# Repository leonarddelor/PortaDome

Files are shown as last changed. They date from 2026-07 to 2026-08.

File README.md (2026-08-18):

# PortaDome

Dôme démontable de **25 haut-parleurs** diffusant une bande son **synchronisée à l'échantillon
près** sur toutes les voies. Projet étudiant, ~1 an, rythme soutenu.

Le parti pris qui commande tout le reste : **une seule Teensy est le cerveau**, maître d'horloge
unique pour les 25 voies via 2 ports TDM. Rien d'autre n'a d'horloge propre — c'est ce qui interdit
la dérive entre haut-parleurs voisins.

---

## ⚠️ État au 2026-08-18 — à lire avant tout

Le dépôt contient **deux générations de carte ampli**. Ne pas les confondre :

| | Carte proto mono-puce | **Carte ampli v2** |
|---|---|---|
| État | Routée, gerbers vérifiés | **À concevoir** |
| Commandée ? | **Non, et ne le sera pas** | pas encore |
| Rôle aujourd'hui | **Référence** — valeurs vérifiées au datasheet et défauts trouvés | la carte qu'on construit |

**Le proto ne sera pas fabriqué.** Le projet a de l'avance, et une session de conception système le
18/08 a fait apparaître cinq écarts entre cette carte et ce dont le dôme a besoin — tous sur ses
**interfaces**, aucun visible en relisant son schéma. La refonte les corrige d'un coup.

Le document du proto reste précieux : il porte les valeurs vérifiées contre le datasheet et
l'historique des défauts trouvés, qui ne doivent pas être refaits.

---

## Ce qu'on construit

```
Ordinateur (USB)  ─┐
                   ├─► Teensy 4.1 ─TDM/I2C─► 3 cartes mères × 4 cartes ampli ─► 24 HP 8 Ω
Carte SD (secours) ─┘        (maître          + 1 carte MCU × 1 carte ampli   ─► 1 sub 4 Ω
                              d'horloge)         (PBTL)
```

Le tout dans un **rack 19" 3U ventilé**, cartes ampli **debout et débrochables**, sorties en
**Speakon NL4**. Budget estimé : **~920 $** hors haut-parleurs.

---

## Les documents

| Fichier | Ce qu'il contient |
|---|---|
| [`docs/architecture-systeme.md`](docs/architecture-systeme.md) | **Commencer par là.** Carte des décisions sur 9 sous-systèmes : ce qui est décidé, ce qui est ouvert, et le graphe de ce qui bloque quoi. |
| [`docs/proposition-carte-octo-dome.md`](docs/proposition-carte-octo-dome.md) | Proposition technique. Le §7 porte le cahier des charges de la carte ampli v2. |
| [`docs/mecanique-coffret.md`](docs/mecanique-coffret.md) | Rack 3U, cartes debout, ventilation push-pull, connectique. |
| [`docs/proto-ampli-tas5825m.md`](docs/proto-ampli-tas5825m.md) | Suivi du proto. **Le §7 liste les défauts trouvés** — à ne pas refaire. |
| [`docs/carte-adaptation.md`](docs/carte-adaptation.md) | Le slot de carte mère construit seul, pour tester les cartes ampli au banc. |
| [`docs/diagnostic-et-maintenance.md`](docs/diagnostic-et-maintenance.md) | Ce que les puces savent dire d'elles-mêmes, et le client USB de réglage et de dépannage. |
| [`docs/budget-coffret.html`](docs/budget-coffret.html) | Chiffrage par poste, avec niveau de confiance par ligne. |
| [`docs/projet-etudiant-feuille-de-route.md`](docs/projet-etudiant-feuille-de-route.md) | Méthode de travail, conventions git, glossaire. |
| [`mecanique/implantation-3u.scad`](mecanique/implantation-3u.scad) | Étude d'encombrement paramétrique. `F5` dans OpenSCAD, lire la console. |
| [`mecanique/references-step-et-cotes.md`](mecanique/references-step-et-cotes.md) | Où trouver chaque STEP, et quelles cotes sont vérifiées ou estimées. |

---

## Le travail à faire

Cinq chantiers. Les phases B et C **ne dépendent de rien** et peuvent démarrer immédiatement.

### A · Carte ampli v2 — le chemin critique

1. **Nettoyer le schéma existant.** Trois références LCSC manquantes (10 kΩ, 4,7 kΩ, 1 µF) et une
   contamination : la référence du 470 nF a été recopiée sur des lignes déclarées 100 nF et 680 nF.
   À corriger avant de dupliquer le projet, sinon ça se propage.
2. **Modifier le schéma** : router `PDN`, `FAULTZ`, `WARNZ` et `ADR` vers le connecteur ; supprimer
   CN1 et U3 ; passer les 22 µF PVDD en CMS ; strap PBTL **après** le filtre LC.
3. **Router en 4 couches**, plan GND continu en couche 2, connecteurs sur le bord inférieur
   (2×4 puissance + 2×8 signal), vias thermiques **dans l'empreinte** de U1.
4. **Exporter en STEP** → débloque la phase D et donne la cote la plus critique du projet : la
   hauteur du composant le plus haut, dont dépend le canal d'air de 8 mm entre cartes.
5. **Commander**, avec la carte d'adaptation ci-dessous.

### B · Carte d'adaptation 1 slot — à concevoir en parallèle

La carte v2 n'a plus de bornier : elle ne peut être testée qu'enfichée. Or la carte mère n'existera
pas avant des semaines, et les fils Dupont (~1 A) ne supportent ni les 3,4 A de PVDD ni les 2,1 A de
sortie.

Un petit 2 couches portant les deux embases femelles, un bornier PVDD, un bornier HP, un header
signaux vers XIAO ou Teensy 3.6, la résistance ADR et des trous de fixation. ~10 $ les 5.

**Cette carte est un slot de la carte mère.** La concevoir valide le circuit du slot avant de le
répliquer ×4 — c'est isoler les variables, pas faire un détour.

### C · Firmware et client — indépendants de tout le matériel

Peut démarrer aujourd'hui. Init I2C du TAS5825M à réécrire (le driver Sonocotta cible le TAS5805M),
configuration des GPIO0/1/2 en `WARNZ`/`FAULTZ` (registres `60h`-`63h`), I2S stéréo d'abord puis
TDM, répartition des slots conforme à `architecture-systeme.md` §4.

Côté ordinateur, un **client USB** de réglage et de dépannage (voir
[`diagnostic-et-maintenance.md`](docs/diagnostic-et-maintenance.md)). La Teensy n'est qu'un relais
I2C : toute l'intelligence est dans le client, ce qui permet d'itérer sur les réglages **sans
reflasher**.

### D · Mécanique — après l'export STEP

Assemblage FreeCAD à partir des vrais modèles (voir `mecanique/references-step-et-cotes.md`).
Vérifier en priorité le **canal d'air réel entre deux cartes voisines** : estimé à 8 mm, et le pas
de 20 mm ne peut pas être élargi sans faire déborder le rack.

### E · Carte mère ×4 — après validation du slot en phase B

4 couches avec plan PVDD (13,6 A pour 4 slots), buck 24 V → 3,3 V, multiplexeur I2C, `FAULTZ`/`WARNZ`
câblés en OU, adressage par slot.

---

## Les deux décisions qui débloquent le plus

1. **Choisir le haut-parleur.** L'impédance est figée (8 Ω), le modèle non. Budget d'alimentation,
   section des câbles et géométrie du châssis en dépendent tous.
2. **Acheter ou fabriquer le châssis.** L'écart va de 60 à 250 $, soit près de 20 % du budget.

## Le piège connu

**~10 mF de capacité de réserve cumulée** sur 13 cartes. Une alimentation de 350 W part en sécurité
ou fait disjoncter au premier allumage, et aucune précharge n'est prévue. C'est le seul défaut de la
liste qui se manifeste par « rien ne démarre » sans indiquer sa cause. Solution notée : séquencer
les 3 cartes mères à ~200 ms d'écart, plus une NTC.

---

## Conventions

Un commit = une idée ; le message explique **pourquoi**, pas seulement quoi. Toute affirmation
matérielle (broche, référence, valeur de registre) se recoupe contre le datasheet officiel — y
compris celles produites par un assistant. **La mesure gagne sur l'affirmation.** Les décisions se
consignent dans les documents datés, pas dans un historique de conversation.

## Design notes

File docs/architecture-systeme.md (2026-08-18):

# Architecture système — carte des décisions

> Document créé le 2026-08-18. Complément de [`proposition-carte-octo-dome.md`](./proposition-carte-octo-dome.md)
> (la proposition technique) et de [`proto-ampli-tas5825m.md`](./proto-ampli-tas5825m.md) (le suivi
> de la carte ampli). Ceux-là décrivent **ce qu'on fait** ; celui-ci décrit **où on en est et ce qui
> bloque quoi**.

## 0. Pourquoi ce document

Le 2026-08-18, une conversation sur la finalité du système a fait apparaître cinq déviations entre
ce qui était conçu et ce dont le projet a besoin : PDN non routé, connecteur à une seule masse, carte
sub bridgée incompatible avec le choix 8 Ω, origine du 3,3 V non tranchée, selfs sous la spec TI.

**Aucune ne venait de la relecture du schéma ou du PCB.** Toutes sont des questions d'**interface**,
et chaque bloc était correct isolément. C'est la raison d'être de ce document : rendre visibles les
frontières entre sous-systèmes, parce que c'est là que se logent les erreurs qu'aucune DRC ne voit.

**Comment le lire** : chaque sous-système donne ce qui est **décidé**, ce qui est **ouvert**, et
**ce dont il dépend**. La §10 donne l'ordre dans lequel les décisions doivent tomber.

## 1. Vue d'ensemble

```
   Source audio                 Cerveau                Distribution           Puissance      Acoustique
  ┌────────────┐          ┌────────────────┐      ┌──────────────────┐    ┌──────────┐   ┌──────────┐
  │ Ordinateur │──USB────►│                │      │ Carte mère 1     │───►│ 4× ampli │──►│ 8 HP     │
  │ (DAW/Max)  │          │  Teensy 4.1    │─TDM─►│ Carte mère 2     │───►│ 4× ampli │──►│ 8 HP     │
  └────────────┘          │  maître        │ I2C  │ Carte mère 3     │───►│ 4× ampli │──►│ 8 HP     │
  ┌────────────┐          │  d'horloge     │      │ Carte MCU        │───►│ 1× ampli │──►│ 1 sub    │
  │ Carte SD   │─────────►│                │      └──────────────────┘    └──────────┘   └──────────┘
  └────────────┘          └────────────────┘                 ▲
                                                             │
                                              ┌──────────────┴───────────────┐
                                              │  Alim 24 V  +  3,3 V         │
                                              └──────────────────────────────┘
```

25 voies = 24 (3 × 8) + 1 caisson.

## 2. Haut-parleurs

**C'est le bloc qui commande tous les autres, et c'est le moins avancé.**

- ✅ **Décidé** : **8 Ω**, figé le 2026-08-18. 25 transducteurs (24 + 1 caisson).
- ❌ **Ouvert** : modèle, puissance admissible, rendement, diamètre, profondeur, type de fixation,
  impédance du caisson (4 Ω ou 8 Ω — voir §3).
- ⛔ **Bloque** : le budget d'alimentation (§6), la section des câbles (§7), la géométrie du châssis
  (§8), et la puissance réellement utile par voie.

**Repère de dimensionnement** : la chaîne délivre **~30 W/voie** à 8 Ω sous 24 V (datasheet
Figure 10-2, 1 % THD). Un HP admettant moins que ça en continu devient le facteur limitant ; un HP
admettant beaucoup plus est de l'argent dépensé pour rien.

## 3. Chaîne d'amplification

- ✅ **Décidé** : TAS5825M, 13 cartes (12 + 1 sub), topologie 3+1, ~30 W/voie, carte sub identique
  aux autres avec strap PBTL + réglage registre, parallélisation **après** les selfs.
- ❌ **Ouvert** : les 8 points du cahier des charges et les 4 décisions de routage, tous détaillés en
  [spec §7](./proposition-carte-octo-dome.md).
- ⚠️ **Le proto mono-puce ne sera pas commandé** (voir [proto §0](./proto-ampli-tas5825m.md)). On
  passe directement à la carte définitive.
- ⚠️ **Carte d'adaptation 1 slot à concevoir** — relevé le 2026-08-18. En supprimant CN1 et U3, la
  carte v2 perd ses deux seuls points de branchement : elle ne peut plus être testée qu'enfichée.
  Or la carte mère n'existera pas avant des semaines, et les fils Dupont (~1 A) ne supportent ni les
  3,4 A de PVDD ni les 2,1 A de sortie HP. Il faut donc un petit 2 couches portant les deux embases
  femelles, un bornier PVDD, un bornier HP, un header signaux vers XIAO ou Teensy 3.6, la résistance
  ADR et des trous de fixation (~10 $ les 5).
  **Cette carte est un slot de la carte mère** : la concevoir valide le circuit du slot avant de le
  répliquer ×4. Voir le plan de travail du [README](../README.md).
- ⚠️ **Selfs sous-spécifiées** : TI demande 4,4 A, la référence retenue donne 3,1 A nominal.

**Point d'arbitrage restant** : **caisson en 4 Ω ou 8 Ω ?** Le PBTL ne sert qu'en dessous de 4 Ω. En
8 Ω, ne pas bridger et garder la seconde voie de cette carte libre. Dépend de §2.

## 4. Cartes mères

Le sous-système **le moins spécifié alors qu'il porte le plus d'interfaces**. Rien n'en existe
aujourd'hui, ni schéma ni cahier des charges.

- ✅ **Décidé** : 3 cartes mères de 4 slots + 1 carte MCU portant 1 slot. Chacune porte le buck
  24 V → 3,3 V de ses cartes ampli, le strapping ADR par slot, et le câblage en OU des FAULTZ/WARNZ.
- ❌ **Ouvert** : tout le reste — dimensions, connectique d'entrée, distribution PVDD interne,
  fan-out du bus TDM vers 4 slots, fixation mécanique des cartes ampli.

**Deux conséquences de la topologie 3+1, jamais notées jusqu'ici :**

**Adressage I2C.** Le TAS5825M n'offre que 4 adresses (0x4C-0x4F) pour 13 puces. La topologie les
résout élégamment : **une carte mère = un segment de mux**, 4 adresses par segment. Un seul
**TCA9548A** (8 segments) suffit — 3 segments pour les cartes mères, 1 pour le sub, 4 en réserve.
La spec §7 évoquait « 2 mux, ou regrouper » : le besoin est en fait d'**un seul**.

**Répartition des slots TDM.** 12 cartes × 2 voies + 1 sub en mono (**une seule voie**, pas deux)
= **25 slots**, pour 2 ports de 16 :

| Port | Contenu | Slots |
|---|---|---|
| TDM 1 | Cartes mères 1 et 2 | 16 |
| TDM 2 | Carte mère 3 + carte MCU (sub) | 9 |

25 slots pour 25 haut-parleurs, avec 7 slots de réserve sur le port 2. **À vérifier au firmware** :
le découpage doit correspondre au câblage physique, sinon une carte mère entière écoute les mauvais
slots.

## 5. Cerveau (MCU)

- ✅ **Décidé** : **Teensy 4.1** pour le système final, **Teensy 3.6** pour le banc ×4 (déjà en
  possession). Toujours maître d'horloge, quelle que soit la source. 2 ports TDM.
- ❌ **Ouvert** : **comment le bus TDM atteint physiquement 3 cartes mères séparées.** Voir §7 —
  c'est la question qui décide de l'implantation générale.

## 6. Alimentation

Voir [spec §8](./proposition-carte-octo-dome.md) pour le détail.

- ✅ **Décidé** : rail **24 V**. **3,3 V produit par chaque carte mère** (buck 24 V → 3,3 V), ni sur
  la carte ampli, ni depuis le régulateur de bord du MCU.
- ❌ **Ouvert** : précharge, distribution, protection, modèle d'alimentation.

**Le point qui mordra en premier** : ~10 mF de capacité de réserve cumulée sur 13 cartes. Une alim de
600 W part en sécurité ou fait disjoncter au premier allumage. Aucune précharge n'est prévue.
C'est le seul défaut de la liste qui se manifeste par « rien ne démarre », sans indiquer sa cause.

**Budget à recalculer** : les 500-600 W de la spec ont été estimés sur ~38 W/voie. À 30 W réels, le
budget descend. Dépend de §2 (puissance admissible des HP).

## 7. Câblage et implantation

**La décision structurante n'est écrite nulle part : les amplis sont-ils centralisés ou répartis
dans le dôme ?**

| | Ce qui voyage | Difficulté |
|---|---|---|
| **Amplis centralisés** (recommandé) | 25 câbles HP analogiques | Facile — voir barème ci-dessous |
| **Amplis répartis** | Bus TDM à 5-12 MHz sur plusieurs mètres | Difficile, et fragile |

L'analogique se transporte, le TDM rapide non. **Centraliser les 4 cartes dans un coffret** et tirer
du câble HP est la seule implantation qui tienne — mais tant que ce n'est pas écrit, rien ne
l'impose.

- ✅ **Décidé (implicitement, à confirmer)** : câble HP en **1,5 mm²**, **chaque paire torsadée**
  (+ et − du même HP enroulés ensemble — les champs s'annulent, c'est gratuit et c'est la mesure
  anti-rayonnement la plus efficace).
- ❌ **Ouvert** : câblage TDM/I2C entre carte MCU et cartes mères (longueurs, connecteurs, blindage),
  distribution 24 V (topologie étoile ou bus, sections), cheminement.

**Barème câble HP** (résistance aller-retour ≤ 5 % de l'impédance) :

| Section | Longueur max en 8 Ω |
|---|---|
| 0,75 mm² | 8,6 m |
| 1,5 mm² | 17 m |
| 2,5 mm² | 29 m |

Pour un dôme, les liaisons feront 1 à 5 m : **très large en 1,5 mm²**. La longueur n'est pas la
contrainte, le rayonnement l'est — d'où la torsade.

⚠️ Ne pas faire cheminer les câbles HP en parallèle serré avec le bus TDM/I2C ; les croiser à angle
droit si nécessaire.

## 8. Châssis et mécanique

**Entièrement ouvert.** Aucune décision prise, et plusieurs autres blocs en dépendent.

- Structure du dôme : géométrie, matériau, fixation des 25 HP
- Coffret électronique : implantation des 3 cartes mères + carte MCU + alimentation
- **Flux d'air** — la spec §8 le mentionne comme nécessaire, rien n'est conçu
- Fixation des cartes ampli sur les cartes mères : connecteur seul, ou connecteur + vis ?

⚠️ L'entraxe **45 × 51 mm** figé sur le proto n'a de sens que si la carte définitive garde
54,6 × 60,3 mm. Voir §3.

## 9. Source audio et firmware

- ✅ **Décidé** : USB depuis un ordinateur (mode principal), carte SD en socle et secours. Le Teensy
  reste maître d'horloge dans les deux cas.
- ❌ **Ouvert** : init I2C du TAS5825M à réécrire (le driver Sonocotta cible le TAS5805M), lecteur
  multicanal entrelacé démultiplexant vers `AudioOutputTDM`/`AudioOutputTDM2`, configuration des
  GPIO0/1/2 en WARNZ/FAULTZ (registres 0x60h-0x63h), répartition des slots conforme à §4.

**Le firmware ne dépend d'aucun choix matériel restant** — il peut démarrer immédiatement, en
parallèle de la conception des cartes.

## 10. Ordre des décisions

Les flèches se lisent « bloque ».

```
  [2] Haut-parleurs ─┬─► [6] Budget alim ────► modèle d'alimentation
   (8 Ω figé,        ├─► [7] Section câbles
    modèle ouvert)   ├─► [8] Géométrie châssis
                     └─► [3] Sub 4 Ω ou 8 Ω ──► bridger ou non

  [7] Centralisé ou réparti ──► [8] Coffret ──► [4] Dimensions cartes mères
                             └─► [5] Câblage TDM

  [3] 4 décisions de routage ──► [4] Connectique carte mère ──► [8] Fixation
```

**Premier domino : choisir le haut-parleur.** Tant qu'il n'est pas choisi, le budget d'alimentation,
la section des câbles et la géométrie du châssis restent des estimations sans ancrage.

**Deuxième : trancher centralisé vs réparti.** Une ligne dans un document, et elle décide de toute
l'implantation.

Ces deux-là ne coûtent rien à décider et débloquent presque tout le reste.

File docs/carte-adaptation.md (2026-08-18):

# Carte d'adaptation 1 slot

> Créé le 2026-08-18. Petit circuit 2 couches qui reçoit **une** carte ampli v2 et lui donne des
> points de branchement utilisables sur un établi.
>
> Voir [`mecanique-coffret.md`](./mecanique-coffret.md) §4 pour le brochage des connecteurs et
> [`proposition-carte-octo-dome.md`](./proposition-carte-octo-dome.md) §7 pour le cahier des charges
> de la carte ampli.

## 1. Le problème qu'elle résout

En rendant la carte ampli **débrochable**, on lui a retiré ses deux seuls points de branchement :
CN1 (bornier haut-parleur) et U3 (bornier PVDD) disparaissent. Il ne reste que deux embases 2,54 mm
destinées à la carte mère.

Or la carte mère n'existera pas avant des semaines, et il faut bien tester les cartes ampli à leur
réception.

**Les fils Dupont ne peuvent pas faire le pont** : ils sont donnés pour **~1 A**, alors que PVDD
demande **3,4 A** et chaque sortie haut-parleur **2,1 A**. Les signaux numériques passeraient, la
puissance non.

## 2. Elle a trois métiers

C'est ce qui la rend facile à justifier : une seule carte à 2 $ répond à trois besoins distincts.

| | |
|---|---|
| **Banc de test** | éprouver chaque carte ampli à sa réception, avant montage |
| **Prototype de slot** | valider le circuit du slot avant de le répliquer ×4 sur la carte mère |
| **Support d'usage autonome** | ⭐ rendre **une** carte ampli utilisable dans un autre projet |

### Le troisième métier répond à une contrainte déjà posée

Le §6 du document proto énonce que le bloc ampli doit servir **à d'autres projets, où l'on n'en a
besoin que d'une**. Or les décisions du 18/08 avaient discrètement érodé cette possibilité : en
supprimant CN1 et U3 pour rendre la carte débrochable, on l'a rendue inutilisable seule.

La carte d'adaptation restaure exactement cette capacité — et ce n'est pas un hasard, puisqu'une
carte ampli autonome a besoin de la même chose qu'un slot de banc : un bornier PVDD, un bornier
haut-parleur, un accès aux signaux numériques et une adresse I2C.

**Conséquence de conception** : la traiter comme une carte de production, pas comme un bricolage de
banc. Format compact, trous de fixation utilisables, sérigraphie lisible. Et prévoir une **empreinte
de buck 24 V → 3,3 V non peuplée par défaut** : sur carte mère le 3,3 V vient d'en haut, mais dans
un projet autonome l'hôte n'a pas forcément le budget de courant nécessaire. Une empreinte vide ne
coûte rien et rend la paire ampli + adaptation **autosuffisante à partir du seul 24 V**.

## 3. Ce qu'elle est, techniquement

**Un slot de carte mère, construit seul.**

Le circuit du slot — brochage des deux connecteurs, strapping ADR, distribution du 3,3 V, câblage en
OU des FAULTZ/WARNZ — doit être conçu de toute façon. La seule question est de savoir **sur quoi on
le valide** :

| | Sur cette carte | Directement sur la carte mère |
|---|---|---|
| Coût unitaire | ~2 $ | ~28 $ |
| Si le slot a une erreur | on refait une carte à 2 $ | l'erreur est répliquée **4 fois sur 3 cartes**, soit 12 slots faux |
| Correction | une commande | une commande **et** un routage 4 couches à reprendre |

C'est le raisonnement du §1 du document proto — prototyper **une** puce avant quatre. Isoler les
variables, payer l'erreur au prix le plus bas.

Ce n'est donc pas du travail en plus, c'est du **travail avancé** : le schéma se copie-colle ensuite
dans la carte mère.

## 4. Ce qu'elle porte

| Fonction | Composant | Note |
|---|---|---|
| Réception de la carte ampli | 2 embases femelles 2,54 mm (2×4 + 2×8) | le couple accouplé de la carte mère |
| Entrée PVDD | bornier à vis 2P 5,08 mm | `C395868`, déjà en stock — l'ancien U3 |
| Sorties haut-parleur | bornier à vis 4P 5,08 mm | `C2827883`, déjà en stock — l'ancien CN1 |
| Signaux vers MCU | header 2,54 mm simple rangée | fils Dupont vers XIAO S3 ou Teensy 3.6 |
| Adresse I2C | résistance ADR + pont de soudure | valide le mécanisme d'adressage par slot |
| Maintien mécanique | 4 trous M3 | la carte ampli tient debout sur l'établi |
| **Sélection de la source 3,3 V** | cavalier | ⚠️ **hôte OU buck local, jamais les deux** — voir ci-dessous |

⚠️ **Le cavalier 3,3 V n'est pas un confort, c'est une sécurité.** Si l'empreinte du buck est peuplée
*et* que l'hôte fournit son propre 3,3 V par le header, deux régulateurs se retrouvent en opposition
sur le même rail. Le cavalier rend le choix exclusif et visible. Cas typique : branché sur un
Raspberry Pi, on préfère le buck local plutôt que de charger le régulateur du Pi — seule la masse
est alors commune.

**Ajouts propres au banc, à ne jamais mettre dans le rack :**

- **Piquets de test sur BCLK, LRCLK, SDIN** — la §4 du document proto exige déjà une vérification à
  l'oscilloscope (« fronts propres sur BCLK/WS/DATA »). C'est ici qu'on les sort.
- **LED sur FAULTZ et sur WARNZ** — un défaut se voit sans brancher d'ordinateur.
- **Connecteur pour analyseur logique** sur le bus I2C — indispensable pour déboguer l'init du
  TAS5825M, qui est à réécrire entièrement.

## 5. Brancher un hôte

La carte doit servir trois hôtes différents — XIAO ESP32-S3 (le banc documenté en §4 du document
proto), Raspberry Pi, et Teensy 3.6 puis 4.1. Ils n'ont ni le même connecteur ni le même brochage.

**La solution : deux points d'accès câblés sur les mêmes nets**, dont un seul est utilisé à la fois.

| Accès | Format | Pour qui |
|---|---|---|
| **Support XIAO** | embase femelle 2×7, pas 2,54 mm | le XIAO ESP32-S3 s'y enfiche directement |
| **Header générique** | 1×10 ou 2×5, pas 2,54 mm, sérigraphié | Raspberry Pi, Teensy, tout le reste — en Dupont |

⚠️ **Une seule source d'horloge à la fois.** C'est BCLK/LRCLK/SDIN qui ne doivent jamais avoir deux
émetteurs — pas les autres signaux. En mode nœud de production (§6), un Pi et un ESP32 cohabitent
très bien : ils se partagent les rôles au lieu de se disputer le bus. À sérigraphier.

### XIAO ESP32-S3 — enfiché directement

C'est l'hôte principal du banc, et le seul assez petit pour être porté par la carte d'adaptation.
Brochage repris du §4 du document proto, déjà vérifié contre le pinout officiel Seeed :

| Signal | Broche XIAO |
|---|---|
| BCLK | D0 |
| LRCLK (WS) | D1 |
| SDIN (DATA) | D3 |
| SDA | D4 |
| SCL | D5 |
| PDN | **D8** |
| FAULTZ | **D9** |
| WARNZ | **D10** |

D2 est évité (broche de strapping), D6 et D7 restent libres pour garder le moniteur série de debug.
⚠️ Les trois dernières lignes (D8-D10) sont **à vérifier contre le pinout Seeed** avant routage,
comme l'ont été les cinq premières.

**Un atout de l'ESP32-S3** : ses broches I2S ne sont pas figées, elles se choisissent en firmware
via la matrice GPIO. Le routage de la carte peut donc privilégier la propreté du tracé, le firmware
s'adapte — à condition de respecter les broches interdites ci-dessus.

**Source 3,3 V** : cavalier sur « hôte ». Le régulateur du XIAO suffit pour le DVDD d'une seule puce.

### Raspberry Pi — par le header générique

Six signaux plus la masse, vers le connecteur 40 broches :

| Signal | GPIO | Broche Pi | Rôle |
|---|---|---|---|
| BCLK | GPIO18 | **12** | `PCM_CLK` |
| LRCLK | GPIO19 | **35** | `PCM_FS` |
| SDIN | GPIO21 | **40** | `PCM_DOUT` (sortie du Pi) |
| SDA | GPIO2 | **3** | `SDA1` |
| SCL | GPIO3 | **5** | `SCL1` |
| GND | — | **6, 9, 14, 20, 25, 30, 34, 39** | au moins deux, dont une près des horloges |
| PDN *(opt.)* | GPIO4 | 7 | |
| FAULTZ *(opt.)* | GPIO27 | 13 | en entrée |
| WARNZ *(opt.)* | GPIO22 | 15 | en entrée |

Pi et carte sont tous deux en 3,3 V, aucune adaptation de niveau.

⚠️ **Ne pas relier la broche 1 (3,3 V) du Pi.** Peupler le buck local, cavalier sur « buck », et ne
partager que la masse — le régulateur du Pi est déjà sollicité.

**Configuration Linux** — dans `/boot/firmware/config.txt` :

```
dtparam=i2c_arm=on
dtoverlay=hifiberry-dac
```

`hifiberry-dac` déclare un **DAC I2S générique sans contrôle I2C** : le noyau se contente de sortir
de l'I2S en maître d'horloge, et le TAS5825M se configure depuis l'espace utilisateur. Aucun pilote
ASoC à écrire.

⚠️ **Piège d'ordonnancement.** Le datasheet §9.5.3.1 exige *horloges stables d'abord, init I2C
ensuite*. Or les horloges du Pi ne tournent que pendant un flux ouvert. La séquence qui marche :

```bash
aplay -D hw:0 -f S16_LE -r 44100 -c 2 /dev/zero &   # 1. lance les horloges
python3 init_tas5825m.py                            # 2. init, horloges presentes
aplay -D hw:0 fichier.wav                           # 3. lecture reelle
```

Initialiser avant d'ouvrir le flux échoue **silencieusement** — la puce ne voit pas d'horloge.

**Ce que le Pi donne** : deux voies, de quoi valider l'init I2C, lire les registres de diagnostic et
entendre du son. **Ce qu'il ne donne pas** : le TDM multicanal (le pilote est en pratique limité à
deux voies) ni une horloge propre (diviseur fractionnaire, donc jitter). Bon banc, mauvaise cible —
mais ce qu'on y valide se transpose tel quel sur la Teensy, même puce et même init.

## 6. Trois modes d'emploi

Le support 2×7 change complètement le rôle de la carte selon ce qu'on y met et le firmware qu'on y
charge.

| Mode | MCU sur la carte | Usage |
|---|---|---|
| **Slot passif** | absent | carte mère PortaDome — tout vient du connecteur |
| **Banc** | XIAO **hôte** | test des cartes, développement firmware |
| **Nœud de production** | ESP32 **superviseur** | le Pi fait l'audio, l'ESP32 supervise |

### Le mode superviseur, et ce qu'il répare

En production sur Raspberry Pi, l'ESP32 ne fait pas l'audio : il surveille. Répartition des rôles :

| Signal | Piloté par |
|---|---|
| BCLK, LRCLK, SDIN | **Pi** — la source audio |
| SDA, SCL | **ESP32 seul** |
| PDN | **ESP32** |
| FAULTZ, WARNZ | **ESP32** |

Le Pi ne touche jamais à l'I2C : s'il veut changer un réglage, il le demande à l'ESP32 par UART ou
USB. On évite ainsi le multi-maître I2C, fiable en théorie et pénible en pratique.

**Ce que ça répare, concrètement :**

1. **Le piège d'ordonnancement du §5 disparaît.** L'ESP32 surveille l'apparition des horloges — en
   lisant `CLKDET_STATUS` / `BCK_MON`, ou en observant BCLK — et lance l'init **au bon moment, tout
   seul**. Plus personne n'a à se souvenir d'ouvrir un flux avant d'initialiser.
   *(Ce bug a coûté une semaine de recherche en conditions réelles. Il ne doit pas pouvoir revenir.)*
2. **La mise en veille du Pi devient sûre.** Quand le Pi dort ou redémarre, les horloges s'arrêtent
   et le TAS5825M se retrouve dans un état indéterminé. Le superviseur détecte la perte, met en HiZ
   pour éviter le claquement, et ré-initialise au retour — sans que le Pi ait à y penser.
3. **Le nœud reste diagnosticable même Pi éteint** : présence I2C, `PVDD_ADC`, défauts.

### L'ESP32 peut-il envoyer le son lui-même ?

Oui, et ça pose une question qui vaut d'être tranchée : **si l'ESP32 fait l'audio, le Pi est-il
encore nécessaire ?**

| Voie | Faisabilité | Remarque |
|---|---|---|
| **Fichiers sur carte SD** | ✅ | Le XIAO S3 « Sense » a un lecteur microSD ; le modèle nu n'en a pas |
| **Flash interne** | ⚠️ | 8 Mo ≈ **45 s** de stéréo 44,1 kHz/16 bits non compressé. Décoder du MP3/AAC allonge beaucoup |
| **Streaming WiFi** | ✅ | C'est la voie naturelle pour un nœud en réseau. **Snapcast** résout la synchro multi-pièces et des clients ESP32 existent |
| **USB Audio Class** | ⚠️ | L'S3 a l'USB natif, mais l'UAC sur ESP32-S3 est peu mûr — à éprouver avant de compter dessus |
| **Bluetooth A2DP** | ❌ | **L'ESP32-S3 n'a pas le Bluetooth Classic**, seulement le BLE. Pas de récepteur A2DP. Il faudrait un ESP32 d'origine |

**Conséquence** : pour un nœud simple — streaming réseau ou lecture de fichiers — **ESP32-S3 + carte
ampli + carte d'adaptation suffisent, sans Pi**. Le Pi ne se justifie que si l'on a besoin de Linux :
DSP lourd, vrai système de fichiers, services réseau, vidéo.

⚠️ **Deux réserves.** Le budget de broches du XIAO est serré (11 GPIO : I2S 3 + I2C 2 + PDN/FAULT/
WARN 3 = 8, il reste peu pour une SD en SPI). Et l'horloge I2S de l'ESP32 sort d'une PLL interne :
parfait pour un nœud jouant seul, **inadapté à une synchronisation serrée entre nœuds**.

### ⚠️ Cette architecture est l'inverse de PortaDome — délibérément

PortaDome **interdit toute intelligence locale** : un seul cerveau, un seul domaine d'horloge, parce
que la cohérence de phase à ~100 µs entre haut-parleurs voisins l'exige.

Un réseau de nœuds ESP32 avec redondance mesh est exactement l'opposé : autonomie locale, tolérance
aux pannes, synchronisation lâche.

**Les deux sont justes pour leur problème.** Il ne faut jamais laisser croire que l'une pourrait
servir à l'autre : un mesh ne tiendra jamais la synchro d'un dôme, et le dôme n'a que faire de la
tolérance aux pannes d'un nœud isolé.

## 7. Mécanique : comment tout se tient physiquement

La question se pose ainsi : l'adaptateur doit recevoir la carte ampli **debout**, et se brancher sur
le connecteur du Pi qui est **à plat**. Deux orientations perpendiculaires sur une même carte.

**La sortie est de ne pas empiler. L'adaptateur n'est pas un HAT.**

```
     carte ampli (debout, 60 mm)
            │
      ┌─────┴──────┐
      │ adaptateur │  borniers PVDD / HP, support XIAO
      └─────┬──────┘
            │  nappe 10 points
            │
      ┌─────┴──────┐
      │ Raspberry  │
      │     Pi     │
      └────────────┘

    les deux à plat sur la même platine, côte à côte
```

Les deux cartes se vissent **côte à côte** sur une platine, reliées par une nappe courte. Plus
aucune contrainte d'orientation.

### Pourquoi ne pas empiler est meilleur, et pas seulement plus simple

1. **Hauteur** — une carte de 60 mm dressée au-dessus d'un HAT donne un empilement haut et
   déséquilibré. Côte à côte, tout est stable.
2. **Chaleur** — la carte ampli dissipe, le Pi 4 dissipe. Les superposer, c'est faire chauffer l'un
   par l'autre et priver les deux de circulation d'air.
3. **Bruit** — l'argument décisif. La carte ampli porte du **24 V à 3,4 A commutés vers 400 kHz**.
   La poser sur le Pi met cette commutation à quelques millimètres de son processeur et de ses
   horloges. **Les séparer physiquement est électriquement supérieur.**

Une nappe coûte deux euros et règle les trois.

### Le XIAO est l'exception, à cause de sa taille

21 × 17,5 mm — assez petit pour être **enfiché directement sur l'adaptateur**, sans câble ni
platine. L'ensemble adaptateur + XIAO + carte ampli forme alors un bloc rigide unique qui tient
debout seul.

C'est la raison pour laquelle le support 2×7 est intégré à la carte alors que le Pi passe par un
header : **la différence de taille justifie la différence de traitement.**

### Ce que l'adaptateur demande

- **4 trous M3** pour le visser sur une platine ou un fond de boîtier
- La carte ampli **s'y dresse** — c'est l'adaptateur fixé qui lui donne sa stabilité, pas l'inverse
- Le **header générique orienté vers l'extérieur**, pour que la nappe sorte sans contorsion
- Ni glissière ni renfort : une carte de 60 mm sur deux connecteurs 2,54 mm, portée par un
  adaptateur vissé, tient parfaitement

### Si un jour il faut un produit Pi compact

La bonne réponse ne sera **pas** de plier l'adaptateur en HAT, mais de concevoir un **HAT dédié**
intégrant le circuit ampli directement. On abandonne alors la carte ampli modulaire : c'est un autre
produit, pas une variante de celui-ci.

## 8. Ce qu'elle reste après

Elle ne se jette pas une fois la carte mère faite. Sur un projet d'un an avec 13 cartes :

- **Un slot d'établi permanent** — isoler une carte suspecte, développer du firmware, refaire un
  test sans mobiliser le rack ni démonter le dôme.
- **Le poste de mise en service** — chaque carte neuve y passe avant d'être montée : présence I2C,
  clocks détectées, PVDD correct, un canal à la fois.

## 9. Position de repli

Si l'objection « pourquoi ne pas simplement garder les borniers sur la carte ampli » l'emporte, il
existe une solution honnête : **garder CN1 et U3 sur la première série de cartes v2**, et ne
concevoir la carte d'adaptation qu'au moment de la carte mère.

Ce qu'on perd : le débrochage sur ces premières cartes, ~9 % de surface consommée sur chacune, et la
validation du slot avant réplication. Ce n'est pas absurde — c'est simplement plus cher à terme.

⚠️ Cette position de repli était plus défendable **avant** qu'on identifie le troisième métier. Elle
consiste maintenant à payer 9 % de surface sur treize cartes, définitivement, pour éviter de
concevoir une carte à 2 $ dont on a besoin de toute façon pour l'usage hors dôme.

## 10. À faire

- [ ] Figer le brochage des deux connecteurs (dépend du routage de la carte ampli v2)
- [ ] Prévoir l'empreinte de buck 24 V → 3,3 V, non peuplée par défaut
- [ ] Vérifier D8/D9/D10 du XIAO contre le pinout officiel Seeed
- [ ] Trancher XIAO S3 nu ou « Sense » (lecteur microSD) selon le mode visé
- [ ] Éprouver la maturité de l'USB Audio Class sur ESP32-S3 si cette voie est retenue
- [ ] Schéma
- [ ] Routage 2 couches
- [ ] Orienter le header générique vers l'extérieur du contour (sortie de nappe)
- [ ] Commander **avec** les cartes ampli v2, même lot
- [ ] Une fois validée, copier le circuit du slot dans la carte mère

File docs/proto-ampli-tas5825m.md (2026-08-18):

# Proto ampli TAS5825M — carte mono-puce

> Document de suivi du prototype ampli (lié à [`proposition-carte-octo-dome.md`](./proposition-carte-octo-dome.md)
> §7/§10-11 : option v2 "bancs custom" TAS5825M). Objectif : valider le comportement TDM/I2C réel
> de la puce sur un banc de test léger, avant de concevoir le banc de production 4 puces (8 voies)
> qui sera ensuite rebranché sur la Teensy.
>
> **Schéma final (validé) : [`TAS5825M_BOARD.pdf`](./TAS5825M_BOARD.pdf)** — export EasyEDA, relu et
> corrigé au fil de l'eau (voir §7 pour l'historique des points corrigés).

## 0. État au 2026-08-18 (point de reprise)

> ⚠️ **Décision du 2026-08-18 : cette carte ne sera pas commandée.** Le travail passe directement à
> la carte définitive (spec §7, « Architecture retenue pour le banc ×4 »). Motif : le projet a de
> l'avance, et une carte qui serait remplacée aussitôt coûte ~102 $ et trois semaines d'attente pour
> valider ce que la refonte change de toute façon. Le contenu ci-dessous **reste la référence** :
> schéma relu, valeurs vérifiées au datasheet, et surtout les défauts trouvés — ils ne doivent pas
> être refaits sur la carte définitive.

**Où on en est** : schéma validé, PCB routé, gerbers exportés et relus, **non commandé**.

Ce qui est vérifié sur les gerbers du 2026-08-18, pas seulement dans l'éditeur :

- 4 trous M3 Ø 3,30 mm, entraxe **45 × 51 mm**, rectangle exact, outil de perçage unique
- 381 vias de couture GND (pas ~2 mm), plans de masse sur les deux couches
- Pad 33 de U1 relié à GND, matrice de 16 vias thermiques connectée au plan
- DRC propre, alerte netlist résolue
- Carte : **54,610 × 60,325 mm**

**Ce qui restait à régler, et reste valable pour la carte définitive** :

1. **3 composants sans référence LCSC** — 10 kΩ 0603 (R3-R6), 4,7 kΩ 0603 (R7), 1 µF 0603 (C19).
   Voir le tableau §3.
2. **Incohérences valeur ↔ référence dans la BOM exportée** — la référence du 470 nF a été recopiée
   sur des lignes déclarées 100 nF et 680 nF. Voir §3. **À corriger au schéma**, elle se propagerait
   sinon à la carte définitive.
3. **U2 à basculer** de `C144398` (rupture) vers `C161874` (en stock) — sans objet si le connecteur
   passe en 2×8 comme prévu en spec §7.
4. **Statut Basic/Extended à vérifier** sur [jlcpcb.com/parts](https://jlcpcb.com/parts) — le devis
   portait 28 $ de frais « Extended Components », réductibles en choisissant des pièces Basic.

**Point mineur, non bloquant** : deux filaments de cuivre GND de 57 et 86 µm subsistent près de U1
(sous le minimum de gravure de 0,127 mm), à côté des liaisons manuelles vers les pins 25/26/31.
Correctif connu : passer le clearance de la zone du dessus de 0,254 à 0,30 mm, puis rebuild.
Sans conséquence fonctionnelle — au pire une question DFM de JLCPCB.

## 1. Pourquoi ce proto (rappel de la démarche)

- Le module TAS5825M "du commerce" (~8 $/pièce, ~13 modules) supposé dans la spec §6/§9 n'a **pas
  été trouvé** comme produit assemblé, bon marché, avec TDM + I2C exposés sur pins accessibles
  (voir recherche : seuls des puces nues ou des cartes "intelligentes" avec leur propre MCU
  existent). On construit donc notre propre carte, en réutilisant le bloc DAC déjà validé par
  Sonocotta dans son design "Esparagus/Louder" (`github.com/sonocotta/esparagus-media-center`,
  `hardware/5-esparagus-audio-brick/rev-a`).
- Schémas et datasheet de référence sauvegardés localement dans [`refs/`](./refs/) :
  - [`refs/esparagus-louder-schematic.pdf`](./refs/esparagus-louder-schematic.pdf) — design Sonocotta
    (EasyEDA), source du bloc DAC repris en §3.
  - [`refs/bassowl-hat-schematic.pdf`](./refs/bassowl-hat-schematic.pdf) — design indépendant
    (Darmur, KiCad, HAT Raspberry Pi), utilisé pour croiser les points du §7.
  - [`refs/tas5825m-datasheet.pdf`](./refs/tas5825m-datasheet.pdf) — datasheet officiel TI, source
    d'autorité qui a permis de corriger une erreur de lecture du schéma (voir §7).
- On prototype **1 seule puce d'abord**, pas les 4 du banc final, pour isoler les variables :
  une erreur de valeur de composant coûte un composant à changer, pas une révision de PCB complète.
- Banc de test choisi : un **XIAO ESP32-S3** (déjà en notre possession), pas la Teensy — la Teensy
  3.6 (déjà utilisée en Phase 1) reste la cible finale de firmware, l'ESP32 sert uniquement à
  dérisquer la partie ampli/TDM en parallèle, à moindre coût et plus vite à itérer.
- Le banc mono-puce servira ensuite de bloc réutilisable pour un banc "8 voies" (4 puces), et le
  bloc DAC lui-même est indépendant du cerveau qui le pilote (Teensy en prod, ESP32 en test) — voir
  §6.

### Alternative évaluée et écartée (2026-08-17)

**Pourquoi aucun ampli I2S du commerce ne convient.** L'architecture impose trois contraintes
*simultanées* : du **TDM** (pas de l'I2S stéréo), de l'**I2C accessible** (adresse + DSP par puce),
et **pas de MCU embarqué** (sinon domaine d'horloge propre → dérive entre haut-parleurs, le mode de
défaillance que toute l'architecture existe pour éviter). Chaque produit du marché rate au moins
l'une des trois :

| Produit | Prix | Ce qui bloque |
|---|---|---|
| MAX98357A | ~3 $ | Mono, I2S stéréo simple, ni TDM ni I2C — incapable de partager un bus à 25 voies |
| Sonocotta "Louder ESP32" | ~25-30 $ | Embarque son propre ESP32 → son propre domaine d'horloge |
| HAT Raspberry Pi (BassOwl, HiFiBerry) | ~30-50 $ | Stéréo, et liés au Pi |

**L'alternative réelle**, en revanche, existe : **DAC multicanal parlant TDM + modules class-D
analogiques du commerce** (type TPA3116, ~3-5 $/carte). Un DAC 8 canaux fait le démultiplexage, des
amplis analogiques bêtes font la puissance derrière.

- **Pour** : aucune conception de PCB, aucun QFN, tout en stock permanent.
- **Contre** : (1) **25 liaisons analogiques** entre DAC et amplis — bruit, diaphonie et câblage
  conséquent dans le volume du dôme ; (2) **le DSP par voie disparaît** — les biquads, le DRC, l'AGL
  et les protections thermique/excursion du TAS5825M sur lesquels la spec §7/§9 compte seraient à
  refaire en amont ; (3) plus de boîtiers et de distribution d'alimentation.

**Écartée** pour ces trois raisons, principalement la perte du DSP par voie. **À reconsidérer
sérieusement si le proto invalide le TAS5825M** (init I2C impraticable, TDM instable, thermique
rédhibitoire) — c'est le plan B, et il est crédible.

⚠️ La référence de DAC multicanal TDM n'a **pas** été choisie ni vérifiée sur datasheet : si ce plan B
est réactivé, c'est le premier point à instruire.

## 2. Architecture retenue pour le proto

- **Assemblage complet par JLCPCB PCBA** (changement de plan, voir §5) : tous les composants sont
  posés en usine (QFN de U1 + tous les passifs/connecteurs), plus simple et pas beaucoup plus cher
  qu'assembler seulement U1 à la main. Les 4 résistances ADR restent posées normalement — le choix
  de l'adresse (pont de soudure) se fait à la réception de la carte, indépendamment de qui a soudé
  les résistances.
- **Alimentation simplifiée pour le proto** : PVDD amené directement depuis une alim de labo (pas
  de connecteur DC ni de protection anti-polarité inversée comme sur le design Sonocotta complet).
  Le 3.3V logique est pris depuis le XIAO S3 ou une alim externe, pas généré sur la carte (on saute
  le buck XL1509 du design de référence, pas essentiel pour valider la puce).
- **Pas de connecteur QWIIC** : liaison I2C en fils directs vers le XIAO S3.

## 3. Nomenclature (BOM) — carte mono-puce

Repris du bloc "DAC" du schéma Esparagus (`Louder Esparagus (DUAL POWER)`, feuille 1/3).

### Références LCSC — vérifiées le 2026-08-18

Chaque ligne a été relue sur sa fiche LCSC. **C'est ce tableau qui fait foi**, pas les sous-sections
ci-dessous, qui portent encore d'anciens repères (C29/C30/C40/C41, L7, C44-C48) hérités du schéma
Esparagus et non renumérotés.

| Valeur | Repères | LCSC | Référence fabricant | Stock |
|---|---|---|---|---|
| TAS5825MRHBR | U1 | `C471049` | TI | ✅ 937 |
| 470 nF 0805 50V X7R | C3, C5, C7, C17 | `C335536` | Walsin `0805B474K500CT` | ✅ 6 860 |
| 680 nF 0805 50V X7R | C2, C4, C6, C8 | `C2859297` | Walsin `0805B684K500CT` | ✅ 7 480 |
| 100 nF 0805 50V X7R | C1, C11, C16 | `C83055` | Walsin `0805B104K500CT` | ✅ 199 240 |
| 390 µF 35V SMD | C9, C14 | `C359223` | SAMYOUNG | ✅ 940 |
| 22 µF 50V traversant | C10, C12, C13, C15, C18, C20, C21 | `C28057` | Chengx | ✅ 10 350 |
| 10 µH SMD 7,3×6,6 | L1-L4 | `C280584` | Chilisin `MHCI06024-100M-R8A` | ✅ 545 |
| 1 kΩ 0603 1% | R1 | `C21190` | Uniroyal `0603WAF1001T5E` | ✅ 8,1 M |
| 15 kΩ 0603 1% | R2 | `C22809` | Uniroyal `0603WAF1502T5E` | ✅ 3,8 M |
| 100 kΩ 0603 1% | R9 | `C25803` | Uniroyal `0603WAF1003T5E` | ✅ 13,2 M |
| 0 Ω 0603 | R8 | `C21189` | Uniroyal `0603WAF0000T5E` | ✅ 16,0 M |
| MM1Z15 zener 15V | D1 | `C115219` | Jingdao | ✅ 4 450 |
| AO4407A P-MOS | Q1 | `C16072` | AOS | ✅ 22 665 |
| Bornier 4P 5,08 | CN1 | `C2827883` | DORABO | ✅ 26 465 |
| Bornier 2P 5,08 | U3 | `C395868` | DORABO | ✅ 51 530 |
| JST XH 7P | U2 | `C161874` | JST `B7B-XH-AM(LF)(SN)` | ✅ 535 |

**À trouver avant de commander :**

| Valeur | Repères | Situation |
|---|---|---|
| 10 kΩ 0603 | R3, R4, R5, R6 | `C25804` en rupture — équivalent à choisir |
| 4,7 kΩ 0603 | R7 | `C23162` en rupture — équivalent à choisir |
| 1 µF 0603 | C19 | Aucune référence ni fabricant dans la BOM |

⚠️ **Trois défauts dans la BOM exportée à corriger au schéma :**

1. **Référence recopiée sur la mauvaise valeur.** Le code EIA `474` vaut 470 nF. Il apparaît sur des
   lignes déclarées 100 nF (C1, C11, C16 — devrait être `104`) et 680 nF (C2, C4, C6, C8 — devrait
   être `684`). Les valeurs du schéma sont bonnes ; ce sont les références fabricant qui ont été
   mélangées.
2. **C18** est un 22 µF dans la BOM exportée, alors que la sous-section « découplage » ci-dessous
   l'annonce à 4,7 µF. La BOM vient du schéma : c'est elle qui a raison.
3. **U2 pointait sur `C144398`** (B7B-XH-**A**, en rupture) et non sur le `C161874` annoncé dans la
   doc (B7B-XH-**AM**, en stock). Même série, 7 positions, pas de 2,5 mm, même boîtier XHP-7 côté
   câble — mais comparer les dessins mécaniques avant de basculer, le suffixe `AM` change le
   moulage du corps.

Note d'assemblage : **10 composants traversants** (7 condensateurs radiaux + les 3 connecteurs).
JLCPCB les facture en soudure manuelle, séparément du CMS — à vérifier sur le devis.

### Puce

| Réf. | Composant | Notes |
|---|---|---|
| U3 | TAS5825MRHBR (VQFN-32, 5×5mm) | LCSC **C471049** (en stock, ~2.57 $/pièce à l'unité) — seul composant à faire assembler / souder à l'air chaud |

### Condensateurs de bootstrap (obligatoires — corrigé après vérification datasheet, voir §7)

Datasheet TAS5825M §10.1.2 : chaque demi-pont (BST_x) a besoin d'un condensateur **0.47 µF entre
BST_x et son OUT_x correspondant** pour générer la tension de grille du NMOS high-side. Ce ne sont
**pas** des composants de filtre — je les avais mal classés dans une première lecture du schéma.

| Réf. | Valeur | Rôle |
|---|---|---|
| C29 | 470 nF | Bootstrap BST_A+ ↔ OUT_A+ |
| C30 | 470 nF | Bootstrap BST_A- ↔ OUT_A- |
| C40 | 470 nF | Bootstrap BST_B+ ↔ OUT_B+ |
| C41 | 470 nF | Bootstrap BST_B- ↔ OUT_B- |

### Filtre EMI de sortie (optionnel — confirmé par datasheet §10.1.4)

Le TAS5825M est nativement "inductor-less" ; ce filtre L-C ne sert qu'à réduire les émissions EMI
selon le contexte d'installation, et peut être remplacé par une simple ferrite + condo dans les cas
basse puissance (confirmé par comparaison avec le schéma BassOwl-HAT, qui utilise justement une
ferrite 120R@100MHz au lieu d'une self réelle — deux implémentations valables du même étage).

| Réf. | Valeur | Rôle |
|---|---|---|
| L7, L2 | 10 µH — **Chilisin MHCI06024-100M-R8A, LCSC `C280584`** (4A Isat, SMD 7.3×6.6mm, en stock) | Self, voie A |
| L3, L4 | 10 µH — même référence | Self, voie B |
| C44, C45 | 680 nF | Condo filtre côté sortie, voie A |
| C47, C48 | 680 nF | Condo filtre côté sortie, voie B |

⚠️ Ce filtre est **optionnel** (voir §7) — pour le tout premier test, il est possible de laisser ces
pads vides (sortie directe, sans filtre) et de les peupler seulement une fois la puissance de test
réelle connue. Le 4A de la self ci-dessus couvre ~38W/4Ω (pleine puissance TAS5825M) avec une marge
raisonnable ; un modèle 5.4A (Chilisin `C5577800`) serait mieux dimensionné mais est actuellement en
rupture de stock chez LCSC.

### Alimentation puce (découplage) — liste complète relue depuis le schéma EasyEDA final (C1-C21)

| Valeur | Réf. | Net | Tension recommandée | Rôle |
|---|---|---|---|---|
| 470 nF | C3, C5, C7, C17 | BST_x/OUT_x | 25-35V | Bootstrap (obligatoire, voir §7) |
| 680 nF | C2, C4, C6, C8 | Sortie HP | 25-35V | Filtre EMI optionnel |
| **390 µF** (ou 470µF pour matcher Esparagus) | **C9, C14** | **PVDD (24V)** | **35-50V** | Réservoir bulk PVDD — ⚠️ électrolytique, boîtier nettement plus gros que les autres condos, vérifier la place au layout |
| 22 µF | C10, C12, C13, C15, C20, C21 | PVDD/VCC | 25-35V | Découplage intermédiaire |
| 4.7 µF | C18 | VCC (logique) | 16V | Céramique, décodage zone ADR |
| 1 µF | C19 | VCC (logique) | 16V | Céramique, décodage zone ADR |
| 100 nF | C1, C11, C16 | logique | 16V | Petit découplage |

Confirmé contre le datasheet (§10.1.3 : minimum 22µF sur PVDD, largement respecté) et contre le
schéma de référence Esparagus (qui utilise 470µF, pas 390µF, pour le même rôle — les deux valeurs
sont valables).

### Contrôle / status

| Réf. | Valeur | Rôle |
|---|---|---|
| R10 | 10 kΩ | Pull-up PDN# → 3V3 (actif haut = ampli activé) |
| R12, R13, R14 | 10 kΩ | Pull-ups GPIO0/1/2 → WARNZ/FAULTZ/SDOUT |
| 4 résistances ADR (0Ω, 1k, 4.7k, 15k — une par adresse possible) | 0x4C/0x4D/0x4E/0x4F | Adresse I2C — **table officielle confirmée (datasheet §9.5.2, Table 9-5)**, voir §7. Les 4 sont soudées en permanence, mais **une seule doit être active à la fois** — voir note pont de soudure ci-dessous. |

⚠️ **Important pour le layout PCB** : chaque résistance ADR doit avoir un **pont de soudure ouvert
par défaut** (2 pastilles rapprochées, pas de piste continue) entre elle et GND — pas une piste
soudée d'usine. Si les 4 sont reliées à GND par une piste continue, la résistance 0Ω court-circuite
le nœud ADR en permanence et écrase les 3 autres (adresse bloquée sur 0x4C). Une seule des 4
pastilles-pont doit être fermée (goutte de soudure) après réception de la carte, selon l'adresse
choisie.

### Connecteurs

| Réf. | Composant | Rôle |
|---|---|---|
| CN1 | DORABO DB128L-5.08-4P-GN-S, LCSC `C2827883` (16A, en stock) | Sortie haut-parleur (voie A + voie B) |
| U2 | JST-XH B7B-XH-A(LF)(SN), 7 pos., LCSC `C161874` | Liaison vers le XIAO S3 (détrompé + verrouillage) — voir table de brochage ci-dessous |
| Jumpers PBTL | — | Laissés ouverts (mode stéréo, pas de pont) |

**Brochage U2 (connecteur XIAO S3)** :

| Broche | Signal |
|---|---|
| 1 | VCC (3.3V) |
| 2 | GND |
| 3 | BCLK (SCLK) |
| 4 | WS (LRCLK) |
| 5 | SDIN (DATA) |
| 6 | SDA |
| 7 | SCL |

Boîtier assorti côté câble : **XHP-7** (JST, LCSC `C144406`) + contacts à sertir (série SXH) — ou
câble JST-XH 7 broches pré-serti du commerce (format aussi utilisé comme cordon d'équilibrage LiPo
6S, facile à trouver).

### Alimentation / protection anti-inversion de polarité

| Réf. | Composant | Rôle |
|---|---|---|
| U3 | DORABO DB128L-5.08-2P-GN-S, LCSC `C395868` (18A, en stock) | Entrée PVDD (alim de labo) |
| Q1 | AO4407A, P-channel MOSFET SOP-8, LCSC `C16072` (30V/-12A) | Coupe le courant si la polarité est inversée — Source côté U3 (brut), Drain côté rail PVDD protégé |
| D1 | MM1Z15, Zener 15V SOD-123, LCSC `C115219` | Cathode → Gate, Anode → Source : clampe Vgs pour rester dans la marge de sécurité (±25V max) |
| R9 | 100 kΩ | Tirage Gate → GND (fonctionne avec D1) — ⚠️ ne pas mettre à 0Ω, ça annule la protection (voir erreur corrigée en §7) |

### Optionnel

- **Dissipateur thermique — décision reportée après mesure, pas avant.** Sur un VQFN à pavé exposé,
  la chaleur sort par le **dessous** (pavé → vias → cuivre), pas par le dessus : le dessus du boîtier
  est de la résine, un isolant. Un radiateur collé dessus n'apporterait presque rien. Le vrai
  dissipateur, c'est la matrice de 16 vias sous U1 + les plans de masse cousus (voir §7).
  Chiffres relus au datasheet (§7.4) : R_θJA = **N/A en 2 couches** (TI ne caractérise pas ce cas),
  **30,0 °C/W en 4 couches**, 24,1 °C/W sur l'EVM 4 couches. Une carte 2 couches est donc **au-delà
  de 30 °C/W**, et les ~7 W/puce annoncés dans la spec §8 **ne sont pas dissipables en continu** —
  ce chiffre est un cas sinus-pleine-puissance. (Une première estimation de « 20-30 °C/W en
  2 couches » circulait dans les notes : elle était trop optimiste, les 30 °C/W sont la valeur
  4 couches.) C'est un argument de plus pour passer la carte définitive en 4 couches. Sur du programme musical réel (10-20 dB de facteur de crête) on dissipe
  plutôt 1-2 W, ce que la carte encaisse. ⚠️ Conséquence pratique pour le banc : **ne pas laisser
  tourner un sinus à pleine puissance sans surveiller la température** — c'est le seul scénario qui
  cuit la puce, et c'est un scénario d'établi, pas d'usage. Mesurer avant d'acheter quoi que ce soit.

## 4. Câblage XIAO ESP32-S3 ↔ carte ampli

- Signaux à relier : **BCLK (SCLK), WS (LRCLK), DATA (SDIN)** en TDM/I2S depuis le XIAO, + **SDA/SCL**
  I2C, + **GND commun**, + **PVDD** depuis l'alim de labo (indépendant du XIAO).
- Le XIAO S3 utilise la matrice GPIO de l'ESP32 : les broches I2S/I2C ne sont **pas figées**, elles
  se choisissent en firmware (comme dans les `build_flags` `PIN_I2S_FS/SCK/SD` vues chez Sonocotta).
- **Assignation retenue** (vérifiée contre le pinout officiel Seeed) :

  | Signal | Broche XIAO | GPIO |
  |---|---|---|
  | BCLK (SCLK) | D0 | GPIO1 |
  | WS (LRCLK) | D1 | GPIO2 |
  | DATA (SDIN) | D3 | GPIO4 |
  | SDA | D4 | GPIO5 |
  | SCL | D5 | GPIO6 |

  D2/GPIO3 (strapping pin) évité ; D6/D7 (UART par défaut) laissés libres pour garder le monitor
  série de debug pendant les tests. SDA/SCL sur les pins I2C par défaut (pas de remap nécessaire).
- Câblage en **Dupont acceptable à <20 cm** pour du TDM 8 voies (~5.6 MHz de BCLK), à condition de :
  - coupler **un fil GND à côté de chaque signal individuellement** (BCLK+GND, WS+GND, DATA+GND,
    SDA+GND, SCL+GND) plutôt qu'un seul GND partagé pour tout le paquet ;
  - vérifier les connecteurs Dupont (faux contact = cause n°1 de bug non reproductible) ;
  - garder la **partie puissance (PVDD, sorties HP, filtre LC) en perfboard soudé**, pas en
    breadboard à contacts à ressort (courant réel, commutation class-D).
- Vérification à l'oscillo une fois câblé : fronts propres sur BCLK/WS/DATA, pas de rebond excessif.

## 5. Fabrication

- **Assemblage complet par JLCPCB PCBA** : tous les composants cochés dans la BOM d'assemblage
  (pas seulement U1), chacun lié à sa référence LCSC réelle.
- **Cuivre 1oz retenu** (standard, pas 2oz) : les pistes de puissance (0.6mm) ont déjà de la marge
  pour ~3-4A en 1oz. 2oz coûterait +18$/lot de 5 (+3.60$/carte) pour une meilleure marge
  thermique/courant, mais pas indispensable pour ce proto — **la température sera mesurée** pendant
  les tests plutôt que supposée ; upgrade possible plus tard si les mesures le justifient.
- **Devis réel obtenu (lot de 5 cartes)** :
  - PCB nu seul : **5.35 $**
  - PCB + assemblage complet (tous composants) + envoi : **102 $**
  - Le détail inclut un "Extended Components Fee" de 28 $ (frais par référence classée "Extended"
    chez JLCPCB — composants moins courants nécessitant un chargement manuel sur leurs machines,
    voir explication §7 historique).
  - Estimation (non confirmée par un vrai devis) pour **seulement U1 assemblé** : ~40-45 $ côté
    JLCPCB + ~20-40 $ de composants à acheter séparément sur LCSC pour les souder à la main →
    ~60-85 $ au total, contre 102 $ tout compris. Économie modeste en échange de plusieurs heures
    de soudure manuelle sur 5 cartes — **assemblage complet retenu**.
- Point historique (option abandonnée) : soudure manuelle à l'air chaud du QFN sur adaptateur
  QFN→DIP générique restait possible si on avait gardé le plan "U1 seul assemblé" — pas retenue,
  voir ci-dessus.
- **Comparaison avec une carte du commerce** : ~20.40 $/carte (102 $ / 5) est cohérent avec le prix
  du marché pour un circuit ampli équivalent — le "Louder ESP32 Plus" de Sonocotta (~25-30 $/carte)
  inclut en plus un ESP32 (quelques dollars en volume), donc la majorité de son prix vient déjà du
  même circuit ampli que le nôtre. Pas de surcoût lié au fait d'avoir conçu notre propre carte.

## 6. Réutilisabilité du bloc DAC

Le bloc DAC (TAS5825M + filtre LC + décor découplage + adressage ADR) est **agnostique du cerveau**
qui le pilote — il écoute juste un bus TDM + I2C. Deux réutilisations identifiées :

1. **Banc 8 voies pour PortaDome** : 4× ce bloc sur un même PCB, bus TDM/I2C partagé, chaque puce
   sur sa propre adresse (0x0C-0x0F, 4 adresses dispo nativement, pas besoin de mux I2C à ce stade).
   Testé d'abord au XIAO S3, rebranché plus tard sans modif sur la Teensy (3.6 puis 4.1).
   ⚙️ **Comment cette promesse est tenue concrètement** : voir
   [`carte-adaptation.md`](./carte-adaptation.md). En rendant la carte ampli débrochable (suppression
   de CN1 et U3), on l'a rendue inutilisable seule ; la carte d'adaptation lui rend ses points de
   branchement — bornier PVDD, bornier haut-parleur, accès aux signaux, adresse I2C — et permet donc
   l'usage à une seule carte hors du dôme.
2. **Piste "instrument autonome" (hors PortaDome)**, façon WVR (`~/repo/wvr`, ESP32 + mémoire
   eMMC/PSRAM pour stocker des échantillons) : même bloc DAC, mais intégré sur un board différent
   avec ESP32 + mémoire embarqués (pas le board "bête" de PortaDome). Piste notée pour plus tard,
   pas engagée tant que le proto PortaDome n'est pas validé.

## 7. Points ouverts / à vérifier avant de graver

- [x] **Câblage BST_A±/BST_B±** — confirmé par le datasheet (§10.1.2) : un condensateur **0.47 µF
  entre chaque BST_x et son OUT_x correspondant**, obligatoire (génère la tension de grille du NMOS
  high-side). Ce sont C29/C30/C40/C41 dans la BOM — voir §3. Ma première lecture du schéma Esparagus
  les avait classés à tort comme "filtre côté puce" ; corrigé.
- [x] **Table résistance ADR → adresse I2C** — confirmée par le datasheet (§9.5.2, Table 9-5) :

  | Résistance ADR → GND | Adresse I2C |
  |---|---|
  | 0 Ω | 0x4C |
  | 1 kΩ | 0x4D |
  | 4.7 kΩ | 0x4E |
  | 15 kΩ | 0x4F |

  (Correction : ma lecture initiale du silkscreen Esparagus avait un appariement différent — le
  datasheet fait foi.)
- [x] **Filtre EMI de sortie** — confirmé optionnel (datasheet §10.1.4, chip "inductor-less" en
  natif) ; self réelle (Esparagus) ou ferrite+condo (BassOwl) sont deux implémentations valables du
  même étage, pas un point à trancher.
- [x] **GPIO précis du XIAO S3** — vérifiés contre le pinout officiel Seeed, voir §4. BCLK=D0/GPIO1,
  WS=D1/GPIO2, DATA=D3/GPIO4, SDA=D4/GPIO5, SCL=D5/GPIO6 (D2 strapping évité, D6/D7 UART laissés
  libres pour le monitor série).
- [x] **Taille/pitch du boîtier** — confirmé via LCSC (C471049) : VQFN-32, 5×5mm, pitch standard
  0.5mm. À revérifier une dernière fois sur le dessin mécanique du datasheet avant achat de
  l'adaptateur QFN si soudure manuelle retenue (précaution, pas un doute réel).
- [ ] Devis JLCPCB réel une fois le schéma posé (l'estimation §5 est indicative — le prix réel du
  composant est meilleur que prévu : ~2.57 $/pièce via LCSC C471049, contre 5-8 $ estimés).
- [x] **Pad 33 (pavé exposé de U1) non relié à GND au schéma** — corrigé le 2026-08-17. La broche
  existait sur le symbole mais était restée en l'air : le pavé formait un **îlot de cuivre
  flottant**, le plan le contournait, et les 16 vias thermiques descendaient vers un second îlot
  isolé. Pénalisant en thermique (dissipation limitée à deux petites plaques au lieu du plan) et en
  EM (surface flottante sous la puce, à côté des nœuds de commutation).
  ⚠️ **Ni la DRC ni le rendu 2D ne signalent ce défaut** — un pad ou un via sans net n'est pas une
  violation de règle. **Test qui fait foi** : le cuivre du dessous doit *toucher* les vias, pas
  faire des arcs de contournement autour.
- [x] **Placement + routage refaits** (2026-08-17) :
  - **Selfs appairées par voie.** Chaque voie est un pont (OUT+/OUT−) : deux moitiés dissymétriques
    empêchent les champs de s'annuler. Avant, chaque voie avait une self à ~8 mm et l'autre à
    ~25 mm ; après, les quatre sont entre 13 et 18 mm. La **symétrie dans la paire** compte plus que
    la distance absolue, et le découplage garde la priorité sur les selfs pour la place la plus
    proche de la puce.
  - **4ᵉ trou de vis près de U3** — le bornier PVDD est le seul composant à recevoir un couple
    appliqué à la main, et il était sur le porte-à-faux. Ce sont les joints du QFN qui paient.
  - **Plans de masse sur les deux couches + 381 vias de couture GND** (pas ~2 mm, resserré autour de
    U1 et le long des pistes OUT), posées avec l'outil **Suture Via**.
- [x] **Alerte "netlist mismatch" résolue** — elle venait de nets assignés à la main sur des vias.
  `Import Changes` la supprime mais **efface du même coup les nets des vias** : c'est un
  aller-retour, pas une correction. La sortie de boucle est l'outil **Suture Via**, qui assigne le
  net lui-même.
  ⚠️ **Règle d'ordre** : tout ce qui n'existe que dans le PCB (nets de vias, couture, régions de
  cuivre) se fait **en dernier**, après le dernier import depuis le schéma.
  Pour le banc ×4 : mettre les vias thermiques **dans l'empreinte** de U1, où elles héritent du net
  du pavé et où aucun import ne peut les effacer.
- [x] **Motif des trous de vis** — relevé sur les gerbers du 2026-08-18 (`Drill_NPTH_Through.DRL`),
  valeurs mesurées et non visées. Carte : **54,610 × 60,325 mm**.

  > **Cote à retenir pour la mécanique du dôme : 4 trous M3, entraxe 45 × 51 mm, centrés sur la
  > carte.** C'est la seule ligne dont le support a besoin — elle doit pouvoir être lue sans ouvrir
  > le PCB.

  Coordonnées depuis le coin **bas-gauche** de la carte :

  | Trou | X (mm) | Y (mm) |
  |---|---|---|
  | haut-gauche | 4,805 | 55,662 |
  | haut-droite | 49,805 | 55,662 |
  | bas-gauche | 4,805 | 4,662 |
  | bas-droite (près de U3) | 49,805 | 4,662 |

  Marges au bord : 4,805 mm à gauche/droite, 4,66 mm en haut/bas. Dégagement de tête : 6,5 mm sans
  cuivre ni composant. Perçage **Ø 3,30 mm, outil unique** (`T01C3.30000`).

  ⚠️ Le champ de diamètre d'EasyEDA Pro est un **rayon** : saisir `1,65` pour obtenir Ø 3,30.

  Deux erreurs corrigées le 2026-08-18, à ne pas refaire au banc ×4 : les quatre trous avaient
  **quatre diamètres différents dont un à 2,451 mm** (un M2,5 parmi trois M3 — aucune vis M3 n'y
  serait passée), et des positions non rectangulaires, décalées jusqu'à 1,016 mm (= 40 mil : trous
  accrochés à une grille impériale à des endroits différents). Une M3 dans un trou de Ø 3,30 n'a que
  **0,15 mm de jeu radial**, donc 1 mm d'écart suffit à empêcher les vis d'entrer dans une platine
  percée sur un rectangle régulier — ce qui compte quand la carte sera répliquée 13 fois.
  **Méthode : coter les trous au clavier, jamais à la souris, et relire les valeurs dans le fichier
  de perçage exporté plutôt que dans l'éditeur.**

## 8. Plan de test

1. Souder/faire assembler la carte mono-puce avec les valeurs de départ ci-dessus.
2. Firmware XIAO S3 (base : `esp32-i2s-bare` de Sonocotta, adapté — leur driver cible le TAS5805M,
   pas le TAS5825M, donc l'init I2C est à réécrire en suivant le datasheet TAS5825M) : test stéréo
   I2S simple d'abord.
3. Une fois le stéréo validé : passer le firmware en TDM (8 slots, 16 bits), toujours sur 1 seule
   puce (elle n'écoutera que ses 2 slots).
4. Dupliquer ×4 (banc 8 voies) une fois les valeurs de composants figées sur le proto mono-puce.

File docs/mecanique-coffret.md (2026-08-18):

# Mécanique du coffret — rack 3U ventilé

> Document créé le 2026-08-18. Troisième volet, avec
> [`architecture-systeme.md`](./architecture-systeme.md) (carte des décisions) et
> [`proposition-carte-octo-dome.md`](./proposition-carte-octo-dome.md) (proposition technique).
>
> **Raison d'être** : la mécanique était le dernier bloc entièrement vide de la carte des décisions,
> et elle y apparaissait trois fois comme dépendance. Elle contraint l'électronique en retour —
> l'orientation des cartes fixe l'emplacement des connecteurs, donc le routage.

## 1. Format — 3U rack 19"

✅ **Décidé.** Rack 19", **3U** (133,35 mm), largeur utile ~450 mm.

Quatre raisons qui se cumulent :

1. **Ventilateurs 120 mm.** À débit égal, un gros ventilateur lent est radicalement plus silencieux
   qu'un petit rapide. Le 2U (~83 mm utiles) imposerait du 80 mm sifflant. Dans un lieu d'écoute,
   c'est le critère décisif.
2. **Alimentation à l'intérieur**, sous ou derrière les cartes mères.
3. **Pas de 20 mm entre cartes** conservé pour la circulation d'air (voir §5).
4. Marge de câblage.

Coût : encombrement et poids. Secondaire pour une installation fixe.

## 2. Implantation générale

✅ **Décidé** : coffret central contenant **3 cartes mères + 1 carte MCU + l'alimentation**.
25 câbles HP en sortent. Les amplis sont centralisés, jamais répartis dans le dôme — le TDM à
5-12 MHz ne voyage pas sur plusieurs mètres, l'analogique oui.

```
   ┌─────────────────────── 19" / 450 mm utiles ───────────────────────┐
   │  ┌──────────┐  ┌──────────┐  ┌──────────┐   ┌──────────────────┐  │
3U │  │ Carte    │  │ Carte    │  │ Carte    │   │   Carte MCU      │  │  flux d'air
   │  │ mère 1   │  │ mère 2   │  │ mère 3   │   │   (Teensy + sub) │  │  ═══════►
   │  │ 4 cartes │  │ 4 cartes │  │ 4 cartes │   │   1 carte ampli  │  │
   │  └──────────┘  └──────────┘  └──────────┘   └──────────────────┘  │
   │  ┌─────────────────────────────────────────────────────────────┐  │
   │  │  Alimentation 24 V (en aval du flux)                        │  │
   │  └─────────────────────────────────────────────────────────────┘  │
   └───────────────────────────────────────────────────────────────────┘
```

❌ **Ouvert** : l'implantation exacte, à dessiner. La contrainte s'est nettement desserrée depuis le
choix de l'alimentation UHP (§6) : **62 mm de large au lieu de 124**, ce qui laisse la place à côté
des ~300 mm des trois cartes mères sans avoir à superposer.

📐 **Modèle paramétrique : [`mecanique/implantation-3u.scad`](../mecanique/implantation-3u.scad)**
— ouvrir dans OpenSCAD, changer une cote, F5, lire la console. Les `echo()` vérifient largeur,
hauteur, profondeur, panneau et ventilation, et affichent OK ou DEPASSE.

**Résultat de la première passe (2026-08-18)** : ça rentre, avec 14 mm de marge en largeur, 44 mm en
hauteur, 98 mm en profondeur. Et surtout — voir §8.3 — **la largeur du rack est consommée par le pas
× 13 cartes (260 mm), pas par les dimensions de la carte ampli**.

**Outils libres pour cette étude** (choisis le 2026-08-18) :
- **OpenSCAD** pour l'étude d'encombrement — c'est du code, donc le fichier **vit dans le dépôt, se
  versionne et se diffe** comme le reste de la documentation. Des boîtes paramétriques suffisent à
  répondre à « est-ce que ça rentre ».
- **FreeCAD** pour l'assemblage réel : EasyEDA Pro exporte le PCB en **STEP**, Mean Well et Neutrik
  publient également des STEP. On assemble des modèles réels, pas des approximations — c'est là que
  les collisions apparaissent.
- **Front Panel Designer** (Schaeffer, gratuit) pour le panneau arrière : il produit un panneau
  réellement fabricable, avec les vraies cotes des 13 Speakon + secteur + USB.

## 3. Cartes ampli — format debout

✅ **Décidé** : les cartes ampli s'enfichent **perpendiculairement** aux cartes mères, comme des
barrettes mémoire.

Bénéfices : peu de nappes, connexions robustes, air circulant entre les cartes, et **cartes
remplaçables** — on en garde une en rechange, on la met à n'importe quelle place (l'adressage I2C
est imposé par le slot, voir architecture-systeme §4).

- **Pas entre cartes : 20 mm** (contraint par la ventilation, voir §5)
- **Hauteur : 60,3 mm** — provisoire, dépend de §8
- **Connecteurs sur le bord inférieur**, bornier HP supprimé du bord supérieur

⚠️ **CN1 et U3 disparaissent de la carte ampli.** Un bornier à vis annule l'intérêt d'une carte
débrochable : il faudrait un tournevis dans le rack et un dévissage avant chaque extraction. PVDD et
sorties HP passent désormais par les connecteurs.

Surface récupérée par la suppression des deux borniers 5,08 mm : **à réinvestir en cuivre**, donc en
dissipation — pas en réduction de taille.

## 4. Connectique

### Carte ampli → carte mère : deux connecteurs séparés

| Connecteur | Format | Contenu |
|---|---|---|
| **Puissance** | 2×4 (8 broches) | PVDD ×2, PGND ×2, OUT_A±, OUT_B± |
| **Signal** | 2×8 (16 broches) | 3V3, BCLK, LRCLK, SDIN, SDA, SCL, PDN, FAULTZ, WARNZ, ADR + 6 GND intercalés |

**La séparation des domaines devient physique** : puissance et numérique ne partagent plus ni
connecteur ni chemin de retour. C'est la réponse structurelle à la question EM d'origine.

Deux broches 2,54 mm en parallèle donnent ~6 A pour 3,4 A demandés sur PVDD.

### Face arrière

- **13 × Speakon NL4**, 2 voies par connecteur → 26 voies pour 25 HP, une en réserve.
  Correspondance exacte : **un NL4 par carte ampli**. La carte sub en PBTL utilise une paire de
  pôles.
- Entrée secteur (CEI) si l'alim est interne
- USB depuis l'ordinateur — embase sur panneau

⚠️ **Speakon, pas jack 6,35.** Un jack TS **court-circuite la sortie pendant l'insertion** (la pointe
frotte la masse) : on stresserait l'étage de sortie à chaque manipulation. Il ne verrouille pas, et
surtout il est **confondable avec un connecteur ligne** — 25 jacks identiques portant du 24 V
d'ampli finiraient par recevoir une sortie de console. Le Speakon existe précisément pour rendre
cette confusion impossible, et il verrouille au quart de tour.

## 5. Refroidissement

✅ **Décidé** : **ventilation forcée en push-pull**, flux **avant-arrière**, parallèle aux faces des
cartes. **2 soufflants de 120 mm en façade + 1 extracteur de 120 mm en face arrière.**

⚠️ **La direction du flux n'est pas un choix.** Les cartes debout créent des canaux orientés
avant-arrière (espacées en largeur, leur longueur suivant la profondeur). Un flux latéral buterait
perpendiculairement sur leur tranche et les contournerait au lieu de les traverser. **Le pas de
20 mm est contraint par la même logique** — resserrer à 15 mm étranglerait les canaux.

**Pourquoi push-pull et pas seulement des soufflants** : les canaux ne font que ~8 mm, c'est un
chemin restrictif. Souffler à l'avant *et* extraire à l'arrière double le différentiel de pression
disponible. Sur un chemin dégagé la différence serait marginale ; ici elle compte.

**Garder plus de débit entrant que sortant** (2 contre 1) maintient le coffret en **surpression** :
l'air n'entre que par les ventilateurs, donc un filtre sert réellement à quelque chose. En
dépression, la poussière entre par tous les interstices et aucun filtre ne la retient.

**Implantation du panneau arrière** : le bloc Speakon est décalé sur la gauche (238 mm) pour libérer
la droite à l'extracteur (120 mm) — total 378 mm sur 450 utiles. Centrer les Speakon ne laisserait
que 106 mm de chaque côté, insuffisant pour un 120 mm.

**Débit nécessaire : faible.** Charge thermique ~75 W (13 puces à ~5 W dissipés + pertes de l'alim).
Pour 10 °C d'élévation il faut de l'ordre de **13 CFM** — un seul 120 mm y suffirait presque à
basse vitesse. Avec trois, la marge est telle qu'ils peuvent **tous tourner très lentement**. C'est
là que se gagne le silence : par la vitesse, pas par le nombre.

**Ce que la ventilation rend** : le budget thermique passe d'environ **27 W à ~40 W continus par
puce** (le θJA baisse quand l'air balaie le cuivre, et l'ambiant interne reste proche de la pièce au
lieu de grimper). ⚠️ **Ordre de grandeur à mesurer, pas à croire.**

**Pilotage** : le MCU dispose déjà de **WARNZ** (routé au connecteur) pour accélérer les
ventilateurs à l'approche du repli thermique. Mieux encore si la puce expose une lecture de
température par I2C — **à chercher dans la table des registres, datasheet §9.6**. Si elle existe, on
régule en continu au lieu de réagir à une alerte.

L'alimentation est placée **en aval du flux**, pour ne pas préchauffer les amplis.

❌ **Ouvert** : référence des ventilateurs et courbe pression/débit (les 8 mm de canal imposent de
regarder la pression statique, pas seulement le débit libre), filtre à l'entrée ou non.

## 6. Alimentation

Voir [spec §8](./proposition-carte-octo-dome.md) pour le dimensionnement.

- ✅ **Décidé** : à l'intérieur du rack. **Mean Well UHP-350-24** — 350 W, 24 V, 14,6 A,
  **220 × 62 × 31 mm**, **refroidissement par convection sans ventilateur**, rendement 94 %.
  (Cotes et absence de ventilateur vérifiées le 2026-08-18 ; à reconfirmer sur la fiche Mean Well
  avant achat.)

  ⚠️ **La série LRS a été écartée** : contrairement à ce qu'on avait supposé, **elle embarque un
  ventilateur dès 350 W** (convection seulement jusqu'à 150-200 W). Un ventilateur de 40 mm dans
  l'alimentation serait la source de bruit la plus aiguë du rack — exactement ce que le choix du 3U
  cherche à éviter. La UHP est en outre **deux fois moins large** (62 contre 124 mm), ce qui résout
  la contrainte d'encombrement du §2.

- **Calibre : 350 W suffisent.** Les 500-600 W de la spec étaient estimés sur ~38 W/voie. À ~30 W
  réels, la consommation moyenne sur programme musical tourne vers ~145 W ; les 10 mF de réserve
  encaissent les crêtes, et le plafond thermique des puces borne de toute façon le régime soutenu.
- ⚠️ **Appel de courant** : ~10 mF de réserve cumulée. Solution offerte par la topologie —
  **séquencer les 3 cartes mères** à ~200 ms d'écart, ce qui divise l'appel en trois paquets de
  ~3,3 mF, combiné à une NTC. Le MCU pilote les relais, ce qui donne au passage un démarrage propre
  (amplis en PDN, I2C configuré, puis activation).
- ❌ **Ouvert** : référence exacte, cotes à confirmer sur la fiche, implantation.

## 7. Visserie et fixation

- **M3 partout.** Motif des cartes ampli : entraxe 45 × 51 mm (provisoire, voir §8).
- ❌ **Ouvert** : hauteur des entretoises (dépend de l'empilage), matière (nylon ou laiton),
  maintien des cartes debout — le connecteur seul suffit-il, ou faut-il des glissières ?

## 8. Ce qui reste à coter

Rien de ce qui suit n'est bloquant aujourd'hui, mais tout doit tomber avant de router.

1. **Largeur de bride et entraxe minimum des Speakon NL4** — dans le DXF/STEP Neutrik. Le cutout
   (24 mm) et les vis (M3) sont confirmés ; l'entraxe ne l'est pas.
2. ~~Cotes exactes de l'alimentation~~ — **fait** : UHP-350-24, 220 × 62 × 31 mm, sans ventilateur.
   À reconfirmer sur la fiche avant achat.
3. ~~La carte ampli garde-t-elle 54,6 × 60,3 mm ?~~ — **l'implantation a répondu (2026-08-18)** :
   **le rack ne contraint ni la longueur ni la hauteur de la carte.**

   | Dimension | Actuelle | Maximum admis par le rack |
   |---|---|---|
   | Longueur (profondeur) | 54,6 mm | **152,6 mm** |
   | Hauteur | 60,3 mm | **~80 mm** (en gardant 25 mm d'air au-dessus) |
   | Épaisseur | ~12 mm | **bornée par le pas de 20 mm — non négociable** |

   La largeur du rack est consommée par **le pas × 13 cartes = 260 mm**, indépendamment des
   dimensions de la carte. Conclusion : **la taille de la carte ampli se décide sur des critères
   électriques et thermiques, plus mécaniques.** L'argument de garder 54,6 × 60,3 (en 4 couches, la
   surface de cuivre **est** le dissipateur) reste donc le seul en lice — et rien n'interdit
   d'agrandir si le routage le demande.

   ⚠️ **Nouvelle contrainte découverte** : les deux condensateurs de 390 µF font **10 mm de haut**.
   Debout sur la carte, avec un PCB de 1,6 mm, l'enveloppe atteint ~12 mm — il ne reste que **8 mm
   de canal d'air** au pas de 20 mm. Or le pas ne peut pas être élargi : à 25 mm, la largeur totale
   passe à ~496 mm pour 450 utiles. Trois pistes, à arbitrer : coucher les électrolytiques, prendre
   du bulk plus plat, ou **déporter la réserve PVDD sur la carte mère** (une par 4 cartes). Cette
   dernière libérerait beaucoup de place et d'épaisseur, mais éloigne le réservoir de la puce — ce
   qui dégrade justement la réponse aux transitoires qu'il sert à tenir.
4. **Maintien mécanique des cartes debout** — glissières ou connecteur seul.
5. **Débit d'air nécessaire**, nombre et implantation des ventilateurs.
6. **Dessin du panneau arrière** — 13 Speakon + secteur + USB.
7. **Hauteurs d'entretoises**, une fois l'empilage dessiné.

## 9. Points de vigilance

- **Bruit de ventilation dans le lieu d'écoute.** C'est le critère qui a imposé le 3U. À vérifier à
  l'oreille une fois monté, pas seulement sur une fiche technique.
- **Bruit de commutation de l'alimentation** à proximité de l'audio. Une LRS est correcte, mais son
  placement compte.
- **Extraction d'une carte sans outil** — c'est tout l'intérêt du format debout. Si le montage final
  demande un tournevis, on a perdu le bénéfice.
- **25 câbles HP en sortie de coffret** : prévoir le maintien mécanique, sinon la contrainte
  remonte dans les Speakon.

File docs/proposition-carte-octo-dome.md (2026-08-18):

# Dôme audio 25 canaux — Spécification

> Spécification technique de référence (2026-06-26). Architecture : **Teensy 4.1 centralisée**.
> Toute évolution = nouvelle version datée.

## 1. Objectif

Diffuser une bande son multicanale **synchronisée au sample** sur un **dôme de 25 haut-parleurs**
(typiquement 2×12 + 1 apex/sub). Le contenu est **mixte** : tantôt décorrélé par HP, tantôt
cohérent entre HP voisins. On dimensionne pour le pire cas : **cohérence de phase ~100 µs entre
HP voisins**.

## 2. Architecture

**Un seul cerveau, des amplis passifs.** Le système contient **un seul microcontrôleur (la
Teensy)**. Les amplis n'ont **ni microcontrôleur ni carte SD** : ils ne font qu'amplifier les voies
que la Teensy leur envoie.

- **Teensy 4.1** = cerveau unique. Elle reçoit les 25 voies depuis **l'une de deux sources** (§6) :
  - **USB depuis un ordinateur** — *mode principal*, pour les intervenants qui jouent en live ;
  - **carte SD locale** — *socle de développement, mode autonome (sans ordi) et secours*.

  Puis elle **démultiplexe** vers **2 ports TDM** (32 voies disponibles). Tout sort d'**un seul
  domaine d'horloge**.
- **Amplification — modules TAS5825M du commerce** (chemin principal) : ~**13 modules stéréo**
  (2 voies chacun) branchés sur le bus TDM de la Teensy, configurés par I2C (via un **mux**). **Rien
  à fabriquer.** Chaque module reçoit les voies numérisées (**TDM + horloge + I2C**) et ne fait que
  les convertir et les amplifier.
- *Option v2* : remplacer les modules par des **bancs « Octo » custom** (4× TAS5825M = 8 voies sur
  un PCB) pour une boîte plus compacte et propre (§11). Non nécessaire pour un dôme qui marche.
- **Synchronisation** : les amplis n'ont pas d'horloge propre, ils sont tous cadencés par la Teensy
  → **les 25 voies sont verrouillées en phase par construction**, **quelle que soit la source**
  (en USB, la Teensy reste maître d'horloge). Seul point à confirmer : l'alignement des deux ports
  TDM (**SAI1↔SAI2**, §5).

```
   ordinateur ──USB──┐  (mode principal)
                     ▼
   ┌──────────────── Teensy 4.1 (cerveau) ────────────────┐
   │  USB (live) ─┐                                        │   amplis TAS5825M
   │  SD (secours)┴─► démux ─► TDM port 1 (16 v) ───────────┼──► [TAS5825M] ─► 2 HP ┐
   │                        └► TDM port 2 (16 v) ───────────┼──► [TAS5825M] ─► 2 HP ├ ~13 modules
   │  BCLK/WS/MCLK partagés ───────────────────────────────┼──►    ...    ─► ...    │ (2 voies / module)
   │  I2C (via mux) ─► config slots/DSP des TAS5825M ───────┼──► [TAS5825M] ─► 2 HP ┘
   └───────────────────────────────────────────────────────┘
        (option v2 : 4 bancs « Octo » de 4 puces, au lieu des 13 modules)
```

## 3. Choix techniques

| Décision | Choix | Justification |
|---|---|---|
| Cerveau | **1× Teensy 4.1** | 2 ports SAI → **32 voies TDM** sur un seul domaine d'horloge. Bibliothèque audio mûre. |
| Ampli (puce) | **TAS5825M** (entrée TDM8) | DAC + puissance + DSP par voie en une puce. |
| Ampli (matériel) | **~13 modules du commerce** (principal) ; **bancs PCB en option v2** | Modules = rien à fabriquer, idéal débutant. PCB = boîte compacte ultérieure. |
| Transport audio | **USB depuis l'ordi (principal)** + **SD locale (socle/secours)** | L'intervenant joue en live depuis sa machine ; la SD assure le dev, le mode autonome et le repli. La Teensy reste maître d'horloge dans les deux cas (cf. §6). |
| Synchro | **Un seul domaine d'horloge** (Teensy) | Verrouillage au sample par construction. |

## 4. Capacité (Teensy 4.1)

- **2 ports SAI**, **TDM 16 voies/port** dans la Teensy Audio Library → **32 voies de sortie**.
  25 voies tiennent avec marge.
- Les 16 voies d'**un même port** sont **sample-locked nativement** (même trame TDM 256 bits).
- Brochage SAI1 (TDM port 1) : MCLK=23, BCLK=21, LRCLK/WS=20, DATA OUT=7 ; I2C SCL=19 / SDA=18.
  Le 2ᵉ port (SAI2/TDM2) a ses propres broches data.

## 5. Synchronisation

- **Tous les amplis partagent l'horloge de la Teensy** (`BCLK/WS/MCLK`) → toutes les voies
  verrouillées en phase par construction.
- **Résiduel interne : SAI1↔SAI2.** 25 voies = 2 ports ; il faut que les deux ports soient
  verrouillés entre eux (sinon les voies 1-16 et 17-32 dérivent). Probablement OK (même PLL audio,
  même cycle d'interruption de la lib), **à confirmer au prototype**.
- **Repli si dérive SAI1↔SAI2** : config TDM **32 slots sur un seul port** (trame 512 bits, BCLK
  ~22,6 MHz à 44,1 k) → un seul domaine, question éliminée.
- **Démarrage** : la Teensy étant maître unique, toutes les voies démarrent sur le même tic.

## 6. Sources audio : USB (principal) et SD (socle/secours)

La Teensy reçoit les 25 voies entrelacées, les démultiplexe et les écoule sur les 2 ports TDM —
**quelle que soit la source**. Elle **reste maître d'horloge dans les deux cas**, donc les voies du
dôme restent verrouillées entre elles (le PC n'a aucune influence sur l'alignement inter-HP).

**USB depuis l'ordinateur — mode principal (intervenants).**
- L'intervenant envoie les 25 voies en live depuis son DAW / Max-MSP. Pas de pré-rendu, temps réel.
- Bande passante : ~2,2 Mo/s (16 bit / 44,1 k), très en-deçà de l'USB 2.0 HS de la Teensy (480 Mbit/s).
- Deux implémentations possibles :
  - **USB Audio multicanal** : la Teensy apparaît comme **carte son** ; nécessite des **descripteurs
    USB custom** au-delà de la stéréo (avancé), mais « plug-and-play » côté PC.
  - **Flux PCM brut sur USB série** : firmware **plus simple** (pas de classe USB Audio), mais
    **émetteur PC à écrire**.
- En USB audio **asynchrone**, la Teensy garde l'horloge maître ; l'écart d'horloge PC↔Teensy est
  absorbé par un **buffer** (impact sur la **latence**, pas sur la synchro du dôme).

**SD locale — socle de dev et mode autonome/secours.**
- Un **seul fichier entrelacé 25/32 voies** sur la SD de la Teensy, lu par blocs et démuxé.
  ⚠️ On n'empile pas 25 `AudioPlaySdWav` (plafond ~2-4) → **lecteur PCM entrelacé custom**.
  Base : **Teensy-WavePlayer** (1-8 voies) puis extension.
- Débit : ~2,2 Mo/s (trivial pour le SDIO Teensy 4.1, >20 Mo/s).
- Rôles : **mode autonome** (install sans ordi, lecture en boucle), **secours** si l'ordi d'un
  intervenant lâche, et **premier jalon de dev** (chaîne TDM validée sans la complexité USB).

> Le **démux vers TDM est commun aux deux sources** : on l'écrit une fois (côté SD), l'USB ne change
> que la provenance des blocs.

## 7. Amplification (TAS5825M)

- **TAS5825M** : ampli classe-D stéréo, **entrée TDM8** (chaque puce/module lit 2 slots), DSP intégré
  (2×15 BQ, DRC, AGL, protection thermique & excursion), PVDD 4,5–26,4 V, jusqu'à ~38 W/voie. Le
  **filtre de sortie LC est déjà intégré** sur les modules du commerce.
- **Chemin principal — modules** : ~**13 modules stéréo** sur le bus TDM partagé, chacun configuré
  par I2C (mode TDM, ses 2 slots, gains, DSP). À l'achat, vérifier que le module **expose I2S/TDM +
  I2C** sur des pins accessibles.
- **Adressage I2C** : les modules ont souvent une **adresse fixe** → un **mux I2C (TCA9548A, 8
  segments)** donne à chaque module son segment (~13 modules → 2 mux, ou regrouper ceux dont
  l'adresse ADR diffère).
- **DSP par voie** : égalisation par position dans le dôme, limiteur et protection en marche autonome.
- *Option v2 (PCB)* : 4× TAS5825M par banc, **filtres LC 10 µH + 470-680 nF**, adressage par broche
  **ADR** (0x4C-0x4F) — cf. §10-11.

### Architecture retenue pour le banc ×4 et le système final (décisions du 2026-08-18)

**Topologie 3+1** : 3 cartes mères recevant chacune 4 cartes ampli (= 24 voies), plus 1 carte MCU
recevant 1 carte ampli **bridgée en PBTL** pour le caisson de grave. Total **25 voies**. La carte
mère est donc répliquée 3 fois, au lieu de câbler 13 modules un par un.

**Impédance des haut-parleurs : 8 Ω — figé.** C'est la décision qui commande tout le reste. À
PVDD 24 V, la sortie en pont donne ~36 W/voie, soit exactement la puissance nominale du TAS5825M.
En 4 Ω, 24 V dépasserait la limite de courant de la puce et imposerait de descendre le rail vers
15-18 V. Le rail 24 V et le budget 500-600 W du §8 découlent de ce choix.

**Le 3,3 V vient de la carte mère, pas du MCU.** La carte ampli est un esclave : sans maître
TDM/I2C elle ne fait rien, donc un maître est toujours présent, et un régulateur par carte ampli
dupliquerait N fois ce que le système possède déjà — pour une place et un routage coûteux à côté
d'un étage class-D. **Pas de buck sur la carte ampli.**
⚠️ Mais pas le régulateur de bord du Teensy ou du XIAO non plus : leur budget est de quelques
centaines de mA, déjà partagé avec le microcontrôleur. La carte mère distribue déjà le 24 V, elle
porte donc un **buck 24 V → 3,3 V pour ses 4 cartes ampli**, et le MCU ne fournit que des signaux.
À dimensionner sur la consommation DVDD du TAS5825M (datasheet) × 4.

**Connecteur à revoir — trois points, tous impactant le routage :**

1. **Masses insuffisantes.** U2 n'a qu'**une seule broche GND** pour cinq signaux, dont une horloge
   à 5-12 MHz. Alterner signal/GND, soit ~11-12 positions au lieu de 7. Le §4 du doc proto applique
   déjà ce raisonnement au câblage Dupont ; il vaut autant en carte-à-carte.
2. **PDN absent — non implémenté aujourd'hui.** Le MCU doit pouvoir remettre les amplis en veille ou
   les redémarrer sans couper le 24 V : indispensable en debug et pour une séquence de démarrage
   propre. À remonter sur le connecteur.
3. **ADR sorti sur le connecteur**, les résistances de sélection restant présentes sur la carte
   ampli mais **non peuplées par défaut** — ce qui donne les deux usages sans compromis :
   - **sur carte mère** → le slot impose l'adresse, et toutes les cartes ampli deviennent
     **identiques et interchangeables** (une carte de rechange se monte à n'importe quelle place) ;
   - **hors carte mère** → on peuple la résistance sur la carte ampli, elle redevient autonome.

   ⚠️ **Jamais les deux sources à la fois** : les résistances se mettraient en parallèle et
   donneraient une adresse fausse. Matérialiser le choix par un pont de soudure explicite.

**Cible MCU** : **Teensy 3.6** pour le banc ×4 (déjà en possession), **Teensy 4.1** pour le système
final.

**Carte sub : identique aux autres, un strap suffit.** Le datasheet documente le mode (Figure 10-8,
« Sub-woofer (PBTL) Application Schematic »). Même schéma, même BOM, même empreinte — un pont fermé
et un réglage de registre. Deux points à respecter :

- **Mettre les sorties en parallèle APRÈS les selfs, pas aux broches de la puce.** TI paralléllise
  aux broches et n'utilise plus que 2 selfs, chacune portant tout le courant. En paralléllisant
  après, les 4 selfs restent en circuit, deux en parallèle de chaque côté, et **chacune ne porte que
  la moitié du courant** — réserve de courant doublée avec les composants déjà présents. C'est ce
  choix qui rend le strap viable, et **il se décide au routage**.
- **PBTL est aussi un réglage I2C** (mode MONO par registre). Le strap câble le cuivre, le firmware
  doit faire le reste. La carte sub occupant un slot connu sur la carte MCU, le firmware le sait par
  sa position — pas de détection automatique à prévoir.

⚠️ **Selfs sous-spécifiées.** TI demande **4,4 A** (Table 10-2, `1274AS-H-100M`). La Chilisin
`C280584` retenue est donnée 3,1 A nominal / 4 A Isat — déjà juste en BTL. En PBTL sur 4 Ω le
courant atteint ~4,25 A : acceptable si la mise en parallèle se fait après les selfs, hors spec si
elle se fait avant. À revoir dans la refonte.

**Puissance réelle par voie : ~30 W.** Figure 10-2 (*Output Power vs PVDD*, 8 Ω, BTL) : à 24 V, ~30 W
à 1 % de THD et ~40 W à 10 %. C'est **30 W** qu'il faut retenir pour le budget d'alimentation, pas
les ~38 W du maximum absolu.

### Carte ampli définitive — cahier des charges (2026-08-18)

Le proto mono-puce **ne sera pas commandé** (voir `proto-ampli-tas5825m.md` §0) : le projet a de
l'avance et la refonte change trop de choses pour qu'une carte intermédiaire serve. Ce qui suit est
ce que la carte définitive doit porter.

1. **4 couches**, plan GND continu en couche 2. Trois raisons qui convergent : TI ne caractérise pas
   le 2 couches thermiquement (§7.4, N/A) ; 16 broches de connecteur au lieu de 7 rendent le routage
   2 couches très contraint ; et un plan continu donne d'emblée ce que 381 vias de couture
   approximaient sur le proto. L'écart de coût chez JLCPCB est de quelques dollars en petite série.
2. **Connecteur signal 2×8 (2,54 mm)** — voir le brochage ci-dessus, GND intercalé sur les trois
   signaux rapides.
3. **PDN routé au connecteur**, pull-up 10 k conservé (garantit « ampli actif » sans maître).
4. **FAULTZ / WARNZ routés au connecteur**, pull-ups conservés (sorties open-drain), câblés en OU sur
   la carte mère. ⚠️ Ce sont des **GPIO configurables** (registres 0x60h-0x63h) : l'init I2C doit
   leur assigner la fonction.
5. **ADR au connecteur**, résistances de sélection non peuplées par défaut + pont de soudure.
6. **Vias thermiques dans l'empreinte de U1** — met fin à la boucle « nets de vias effacés par
   l'import » subie sur le proto.
7. **Condensateurs PVDD 22 µF en CMS 0805**, comme TI les spécifie (Table 10-2), au lieu des
   traversants actuels. Gain triple : plus de surcoût de soudure manuelle chez JLCPCB, moins
   d'inductance parasite sur PVDD, et de la place gagnée. Ce sont 7 des 10 composants traversants
   de la carte.
8. **Selfs à requalifier** (voir ci-dessus).

**Décisions à prendre avant de router** — elles engagent la mécanique autant que l'électronique :

- **Par où entre PVDD ?** ~3,4 A par carte : une broche 2,54 mm est juste, il en faudrait 2-3 en
  parallèle. Un **second connecteur dédié à la puissance** est la solution propre, et isole le bruit.
- **Par où sortent les haut-parleurs ?** Bornier sur la carte ampli, ou renvoi vers la carte mère.
- **La carte garde-t-elle ses dimensions ?** L'entraxe 45 × 51 mm figé sur le proto ne vaut que si
  la carte garde 54,6 × 60,3 mm.
- **Sub en 4 Ω ou 8 Ω ?** Le PBTL ne sert qu'en dessous de 4 Ω. En 8 Ω, ne pas bridger et garder la
  seconde voie libre.

## 8. Alimentation et thermique (cible 20-40 W/voie)

- **Rail PVDD ~24 V**. Bulk caps proches de chaque TAS5825M.
- **Dimensionnement** : fort facteur de crête de la musique → conso moyenne ~1/5 à 1/8 du pic.
  Prévoir la **réserve** pour les pics, pas une alim continue de 25×40 W.
  - Ordre de grandeur : **alim 24 V de ~500-600 W** pour la boîte, à affiner selon le contenu.
- **Thermique** : classe-D ~88 % de rendement → ~7 W/puce à puissance modérée. **Plan de cuivre +
  flux d'air** dans la boîte. Foldback thermique du TAS5825M en protection ultime.

### Points ouverts sur l'alimentation (relevés le 2026-08-18)

Ce qui précède est un dimensionnement d'ordre de grandeur. Tout ce qui se trouve **entre l'alim et
les puces** reste à concevoir :

1. ~~**Impédance des haut-parleurs — non spécifiée.**~~ **Tranché le 2026-08-18 : 8 Ω, figé.** Voir
   §7. Le rail 24 V et le budget 500-600 W ci-dessus en découlent et sont donc validés. Reste à
   choisir le **modèle** de haut-parleur (puissance admissible, rendement, encombrement).
2. **Appel de courant à la mise sous tension.** ~13 modules × 2 × 390 µF ≈ **10 mF** de réserve
   totale. Un SMPS de 600 W part en sécurité ou fait disjoncter sur une capacité pareille. Il faut
   une **précharge / soft-start** (NTC + relais de by-pass, ou alim à démarrage progressif). Rien
   n'est prévu aujourd'hui — c'est le point le plus susceptible de mordre au premier allumage.
3. **Distribution 24 V vers 13 modules** — ~25 A à répartir. Topologie (étoile ou bus), section des
   conducteurs et chute de tension le long du dôme à calculer : 1 V perdu sur le rail, c'est de la
   puissance en moins en bout de chaîne.
4. **Protection** — fusible par module ou par branche. Un ampli en court-circuit ne doit pas
   emporter les 25 voies.
5. ~~**Rail 3,3 V logique.**~~ **Tranché le 2026-08-18** : un buck 24 V → 3,3 V **par carte mère**,
   alimentant ses 4 cartes ampli. Ni sur la carte ampli, ni depuis le régulateur de bord du MCU.
   Voir §7. Reste à dimensionner sur la consommation DVDD du TAS5825M (datasheet) × 4.
6. **Aucune référence d'alimentation retenue** — seulement l'ordre de grandeur 500-600 W / 24 V.

## 9. Coût indicatif (numérique + ampli, hors alim/HP)

| Poste | ~Prix | Total |
|---|---|---|
| Teensy 4.1 | ~32 $ | 32 $ |
| Modules TAS5825M ×13 (2 voies/module) | ~8 $ pièce | ~104 $ |
| Mux I2C (TCA9548A) ×2 + câblage / connecteurs | — | ~12 $ |
| Carte SD | ~8 $ | 8 $ |
| **Sous-total (25-32 voies amplifiées)** | | **~156 $** |

Hors **alimentation 24 V** (~40-60 $) et haut-parleurs.
*Option v2 (bancs PCB)* : ~5 cartes PCBA JLCPCB en remplacement des modules, **coût comparable**.

## 10. Design de référence (option v2 — PCB)

Utile **uniquement si** on conçoit les bancs PCB (option v2). Pour l'étage de puissance TAS5825M :
design open-source `sonocotta/esparagus-media-center`, dossier `hardware/5-esparagus-audio-brick/rev-a`
(réf. TAS5825MRHBR, QFN-32).

**Réutilisable tel quel (×4 par banc) :** étage TAS5825M — PVDD (pins 3/4/21/22), filtre **LC 10 µH +
470-680 nF**, `PDN#`, sorties `GPIOx` (`FAULTZ/WARNZ/SDOUT`), adressage I2C par broche **ADR**,
mode **PBTL** (jumpers) pour bridger une voie apex/sub.

## 11. Fabrication / assemblage

- **Chemin principal : rien à fabriquer.** Teensy 4.1 (module PJRC) + ~13 **modules TAS5825M du
  commerce** + **mux I2C**, reliés par un câblage / fond de panier qui distribue `BCLK/WS/MCLK +
  2 data TDM + I2C + PVDD`. L'effort est du **câblage propre**, pas du PCB.
- **Option v2 (bancs PCB)** : JLCPCB PCBA, lot de **5 cartes identiques** (4× TAS5825M QFN, 4 couches,
  filtres LC, plan PVDD propre) → boîte plus compacte. Base de schéma : §10.

## 12. Firmware (Teensy)

- **Teensy Audio Library**. **Entrée audio** depuis l'une de deux sources : **flux USB** depuis
  l'ordi (mode principal) **ou** **fichier entrelacé sur SD** (socle/secours). Dans les deux cas,
  **démux par blocs** vers `AudioOutputTDM` (port 1) et `AudioOutputTDM2` (port 2).
- **Config TAS5825M par I2C** au boot (via mux) : mode TDM, attribution des 2 slots par puce, gains,
  DSP/EQ par voie, limiteurs.
- Pas de mixage (voies indépendantes). Débit ~2,2 Mo/s, CPU léger (Cortex-M7 600 MHz).

## 13. Risques

- **Flux USB multicanal** (mode principal) : descripteurs USB Audio custom (avancé) **ou** protocole
  série maison + gestion buffer/latence ; dépend de la **machine de l'intervenant** (hors de notre
  contrôle). La **SD sert de repli**.
- **Verrouillage SAI1↔SAI2** : à confirmer (probablement OK). Repli : TDM 32 slots sur 1 port.
- **Lecteur multicanal (SD)** : tâche firmware **bornée** (1 fichier entrelacé + démux) ; c'est le
  socle de dev, pas une fragilité.
- **Adressage I2C de 13 modules** : adresses souvent fixes → **mux I2C (TCA9548A)**.
- **Câblage de 13 modules** : bus TDM + I2C + 24 V + sorties HP → soigner la propreté (l'option v2
  PCB est là pour tasser tout ça si besoin).
- **Point de défaillance unique** (1 cerveau) : garder une **Teensy de rechange déjà flashée**.
- **Thermique** des amplis (classe-D) → ventilation de la boîte.
- **Appro** : verrouiller les références Teensy 4.1 et TAS5825M.

## 14. Prochaines étapes

1. Prototype **Teensy 4.1 + 1 étage 8 voies** (modules) : lecteur entrelacé **depuis SD** + démux →
   8 voies distinctes alignées (scope). *(socle)*
2. Activer le **2ᵉ port TDM** et **mesurer l'alignement SAI1↔SAI2** (< 100 µs, stable) → 25 voies.
3. **Flux USB depuis l'ordi** (mode principal) : alimenter les mêmes 25 voies en live, valider la
   latence et la stabilité ; la SD reste le secours.
4. **Câbler les ~13 modules TAS5825M** + mux I2C sur le bus TDM, les configurer en TDM depuis la
   Teensy, tester les 25 voies amplifiées. *(Option v2 : concevoir les bancs PCB.)*

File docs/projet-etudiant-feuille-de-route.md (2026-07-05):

# Projet « Dôme audio 25 canaux » — Feuille de route étudiant (1 an)

> Document de passation. Public : étudiant·e **débutant·e en électronique/embarqué**, en
> **stage/alternance** (rythme intensif), objectif **dôme complet jouable** en ~12 mois.
> À lire en entier une première fois, puis à garder ouvert comme fil conducteur.
>
> La **spécification technique** est dans [`proposition-carte-octo-dome.md`](./proposition-carte-octo-dome.md).
> Ce document-ci explique **quoi faire, dans quel ordre, et comment travailler**.

---

## 1. Le projet en une page

On veut sonoriser un **dôme** avec **25 haut-parleurs** qui diffusent une bande son **synchronisée
au sample** (tous les HP parfaitement alignés dans le temps).

Faire jouer 25 HP « ensemble » est facile à dire, dur à faire : si plusieurs microcontrôleurs ont
chacun leur horloge, ils **dérivent** l'un par rapport à l'autre (quelques millisecondes en quelques
minutes), ce qui détruit la cohérence du son. **La solution retenue évite le problème** : on met
**un seul cerveau** qui génère toutes les voies sur **une seule horloge**. Tout est verrouillé « par
construction ».

Ce cerveau est une **Teensy 4.1** : une carte microcontrôleur puissante capable de sortir jusqu'à
**32 voies audio** (via une technique appelée **TDM** sur ses 2 ports audio). Elle envoie les voies
à des **amplis** « bêtes » (sans cerveau), qui ne font qu'amplifier. Côté ampli, on utilise des
**modules TAS5825M du commerce** (2 voies chacun) → ~**13 modules** pour 25 voies, **rien à
fabriquer**. *(Une version compacte sur PCB custom reste possible plus tard — option « v2 ».)*

D'où vient le son ? De **deux sources** :
- **un ordinateur, en USB** — *mode principal* : les intervenants jouent en live depuis leur logiciel ;
- **la carte SD de la Teensy** — *socle de développement, mode autonome (sans ordi) et secours*.

**Déjà décidé** (détaillé dans la spec) :
- **Une seule Teensy 4.1** comme cerveau → un seul domaine d'horloge → toutes les voies verrouillées
  ensemble, **quelle que soit la source** (en USB, la Teensy reste maître d'horloge).
- Audio sorti en **TDM** (jusqu'à 32 voies). Entrée : **USB depuis l'ordi** (principal) **ou** SD.
- Amplification par des **modules TAS5825M du commerce** (conversion + ampli + égalisation).
  Option v2 ultérieure : des bancs PCB custom (inspirés du design open-source Esparagus Audio Brick).

**Reste à faire** : la conception, le prototypage et la réalisation, détaillés en §5.

---

## 2. Ce que tu vas apprendre

Ce projet est un terrain d'apprentissage complet. À la fin tu sauras :

- **Git & collaboration** : versionner ton travail, branches, commits propres, pull requests.
- **Travailler avec Claude** (assistant IA) : l'utiliser pour apprendre, concevoir et déboguer —
  **sans lui faire confiance aveuglément** (méthode en §3.2).
- **Programmation embarquée** : C++ sur Teensy (Cortex-M7), lecture de fichiers, audio numérique.
- **Audio numérique** : échantillonnage, I2S, TDM, multicanal, DAC, classe-D.
- **Électronique & PCB** : lire une datasheet, concevoir une carte, la faire fabriquer (JLCPCB),
  la souder/tester, mesurer au multimètre/oscilloscope.
- **Démarche d'ingénieur** : décomposer un gros problème en petits jalons vérifiables, mesurer
  plutôt que supposer, documenter.

> ⚠️ **Honnêteté** : un dôme complet jouable en un an par un·e débutant·e est **ambitieux**. La
> feuille de route est faite pour que **chaque phase soit une victoire en soi**. Si tu prends du
> retard, voir §10 « où réduire le périmètre » — on peut s'arrêter à un jalon valable sans échouer.

---

## 3. Comment travailler

### 3.1 Git (le minimum vital, puis tu approfondiras)

Cycle de base, à répéter tous les jours :

```bash
git pull                      # récupérer les dernières modifs
git checkout -b ma-tache      # créer une branche pour ce que tu fais
# ... tu travailles, tu testes ...
git add -p                    # choisir ce que tu commits
git commit -m "feat: ..."     # message clair au présent
git push -u origin ma-tache   # envoyer sur GitHub
# puis ouvrir une Pull Request sur GitHub pour relecture par ton tuteur
```

Règles : **un commit = une idée**, message qui explique *pourquoi* pas seulement *quoi*, on ne
commit jamais de code qui ne compile pas sur la branche principale. Tiens un **journal de bord**
(voir §3.5).

### 3.2 Travailler avec Claude (méthode)

Claude est un excellent copilote pour ce projet : expliquer un concept, décortiquer une datasheet,
déboguer, rédiger. Mais la règle d'or :

> **Claude propose, tu décides, le matériel tranche.** Une datasheet ou une mesure à l'oscilloscope
> a toujours raison contre une affirmation de l'IA.

Bonnes pratiques :
- **Demande-lui d'expliquer** un concept que tu ne comprends pas (« explique-moi le TDM comme si
  j'avais jamais fait d'audio numérique »).
- **Fais-lui décortiquer une datasheet** ou un schéma, puis **vérifie** les chiffres clés toi-même.
- **Demande des options + une reco**, pas juste une réponse — et garde une trace de la décision.
- **Fige les décisions dans un document** (comme la spec). Ça évite de tourner en rond.
- **Méfie-toi** : il peut inventer un numéro de broche, une référence de composant, une valeur.
  Pour tout ce qui touche le hardware → recoupe avec la datasheet officielle.
- Quand un truc ne marche pas, **donne-lui le message d'erreur complet et le contexte**.

### 3.3 La démarche d'ingénieur (à appliquer à chaque phase)

1. **Comprendre** : lis la datasheet / la doc, fais-toi expliquer.
2. **Prototyper petit** : la plus petite expérience qui teste *une* chose.
3. **Mesurer** : multimètre, oscilloscope, micro + analyseur. Ne *suppose* jamais que ça marche.
4. **Documenter** : ce qui marche, ce qui rate, les valeurs mesurées (dans le journal + le repo).
5. **Itérer** : on monte en complexité seulement quand l'étape précédente est solide.

### 3.4 Sécurité (important, même en basse tension)

- **Soudure** : local ventilé, lunettes, fer ~350 °C, attention aux brûlures.
- **Alimentation** : on travaille jusqu'à ~24 V — pas mortel, mais un court-circuit peut **brûler
  des composants ou démarrer un feu**. Toujours un **fusible** et une alim limitée en courant au
  début. Vérifier la polarité avant de brancher.
- **ESD** : les puces craignent l'électricité statique — bracelet antistatique au montage.
- Ne jamais débrancher/rebrancher l'audio « à chaud » sous tension.

### 3.5 Journal de bord

Crée `doc/journal/` avec un fichier par semaine (`2026-S38.md`…) : ce que tu as fait, ce que tu as
appris, ce qui bloque, les mesures. C'est ton meilleur outil pour le suivi tuteur **et** pour ne
pas réapprendre deux fois la même chose.

---

## 4. Vue d'ensemble de la feuille de route

| Phase | Thème | Durée indic. | Jalon « c'est fait quand… » |
|---|---|---|---|
| 0 | Outils & onboarding | ~3 sem | Tu compiles/flashes la Teensy, premiers commits, journal lancé |
| 1 | Audio sur la Teensy | ~5 sem | Un WAV stéréo joué depuis la SD, son propre |
| 2 | **TDM 8 voies + lecteur multicanal** (point dur) | ~8 sem | 8 voies distinctes en sortie depuis un fichier entrelacé, mesurées |
| 3 | **25 voies / 2 ports TDM** | ~6 sem | 25 voies sorties (depuis SD), alignement SAI1↔SAI2 mesuré < 100 µs |
| 4 | **Flux audio USB depuis l'ordi** (mode principal) | ~5 sem | Un ordi envoie 25 voies en live, jouées et alignées |
| 5 | **Étage d'ampli (modules)** | ~4 sem | ~13 modules câblés + mux I2C, 25 voies amplifiées testées |
| 6 | **Le dôme** | ~10 sem | 25 voies synchrones diffusent une bande son |
| 7 | Finition & démo | ~6 sem | Égalisation par HP, contenu, doc finale, démo publique |

> Les durées supposent un rythme intensif. Le **cœur du risque, ce sont les phases 2 et 3** (sortir
> proprement les 25 voies). Si elles passent, le reste est de l'assemblage. Atteindre **la fin de la
> phase 3** = faisabilité prouvée (résultat déjà soutenable même si le dôme complet glisse).

---

## 5. Feuille de route détaillée

### Phase 0 — Outils & onboarding (~3 semaines)
**But** : être autonome sur l'environnement.
- Installer : éditeur (VS Code), **Teensyduino** (Arduino IDE) ou PlatformIO, Git, un compte GitHub.
- Faire clignoter une LED sur la **Teensy 4.1** (« hello world » de l'embarqué).
- Apprendre le cycle git (§3.1) : faire une vraie PR « j'ai ajouté mon journal ».
- **Livrable** : build/flash OK, première PR fusionnée, `doc/journal/` démarré.

### Phase 1 — Audio sur la Teensy (~5 semaines)
**But** : comprendre l'audio numérique sur du concret, avec un outillage accessible.
- Prendre en main la **Teensy Audio Library** et son **outil de design graphique** (Audio System
  Design Tool) : assembler un flux audio à la souris.
- Jouer un **WAV stéréo** depuis la carte **SD** de la Teensy.
- Comprendre : échantillonnage (44,1 kHz), 16 bits, **I2S** (BCLK/WS/DATA), le traitement par blocs.
- **Livrable** : lecture stéréo propre depuis SD + une page de journal qui explique l'I2S avec tes
  mots.

### Phase 2 — TDM 8 voies + lecteur multicanal (point dur) (~8 semaines)
**But** : sortir **8 voies indépendantes** en **TDM**, alimentées par un **fichier entrelacé**.
- Brancher **un étage 8 voies** : un DAC TDM 8 canaux, ou 4× module **TAS5825M**.
- Configurer `AudioOutputTDM` (16 slots, on en utilise 8).
- ⚠️ **Le vrai morceau** : écrire le **lecteur de fichier entrelacé** (lire un seul fichier
  contenant les 8 voies entrelacées, le **démultiplexer** vers le tampon TDM). On n'empile **pas**
  8 lecteurs `AudioPlaySdWav` (ça ne tient pas). Base utile : **Teensy-WavePlayer**.
- **Mesurer** chaque voie à l'oscilloscope / au casque : distinctes et alignées.
- **Livrable** : 8 voies différentes depuis un fichier entrelacé, son propre. ⭐ *Valide le cœur.*

### Phase 3 — 25 voies / 2 ports TDM (~6 semaines)
**But** : monter à **25 voies** sur les **deux ports TDM** et prouver leur alignement.
- Activer le **2ᵉ port** (`AudioOutputTDM2`) et étendre le lecteur entrelacé à 25 voies.
- **Mesurer l'alignement SAI1↔SAI2** : un « clic » sur une voie de chaque port, comparer au scope.
  Objectif : décalage **< 100 µs** et **stable** dans le temps.
- Repli si les deux ports dérivent : config **TDM 32 slots sur un seul port** (cf. spec §5).
- **Livrable** : 25 voies sorties et alignées (depuis la SD), mesure documentée. ⭐ *Faisabilité prouvée.*

### Phase 4 — Flux audio USB depuis l'ordi (mode principal) (~5 semaines)
**But** : recevoir les 25 voies **en live depuis un ordinateur** par USB, et les écouler sur le TDM.
- Même **démux → TDM** que la phase 3 : seule la **source** change (USB au lieu de la SD).
- Choisir l'implémentation :
  - **USB Audio multicanal** : la Teensy apparaît comme **carte son** côté PC (nécessite des
    **descripteurs USB custom** au-delà de la stéréo — avancé) ; ou
  - **flux PCM brut sur USB série** : firmware plus simple, mais petit **émetteur côté PC** à écrire.
- Gérer le **buffer** : la Teensy reste **maître d'horloge** → la synchro du dôme n'est pas affectée,
  seule la **latence** l'est.
- **Mesurer** : 25 voies live, latence, stabilité dans la durée. La **SD reste le secours**.
- **Livrable** : un ordi envoie 25 voies en live, jouées et alignées sur les sorties.
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

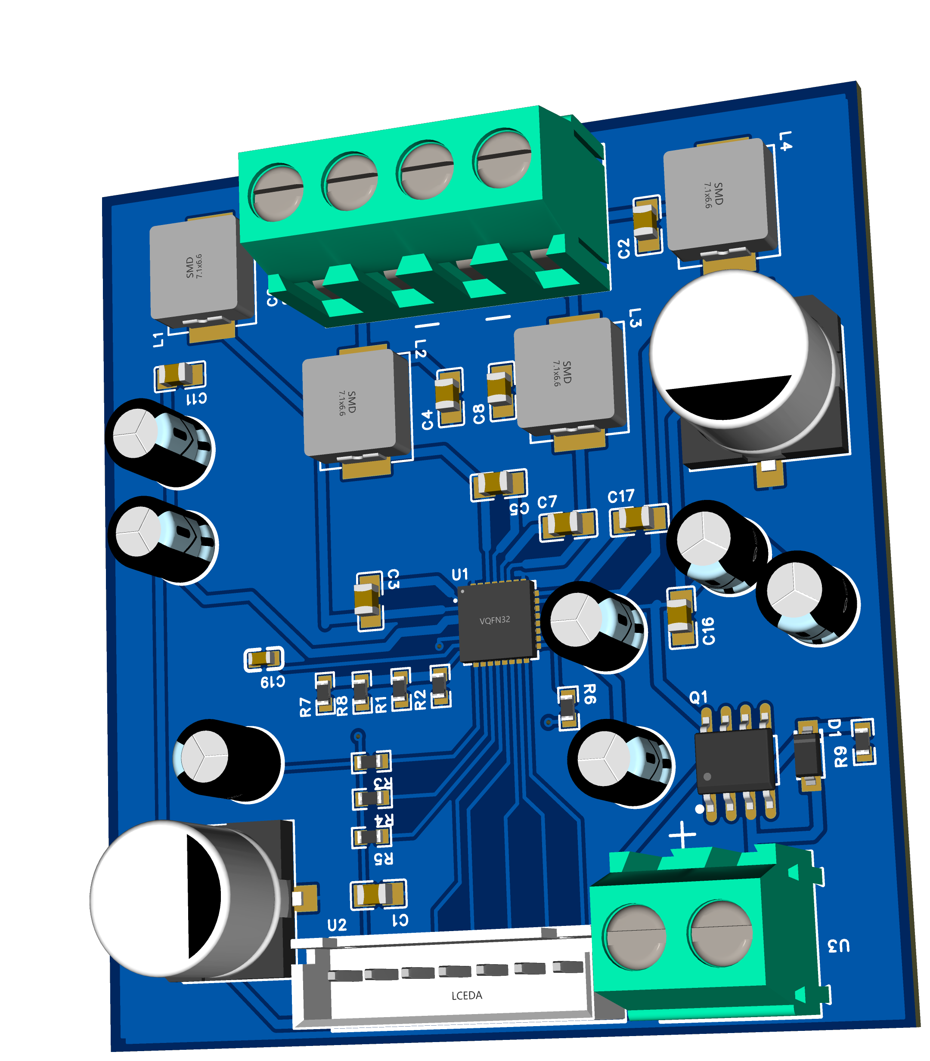
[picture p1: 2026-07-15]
docs/proto-tas5825m-3d-render.png

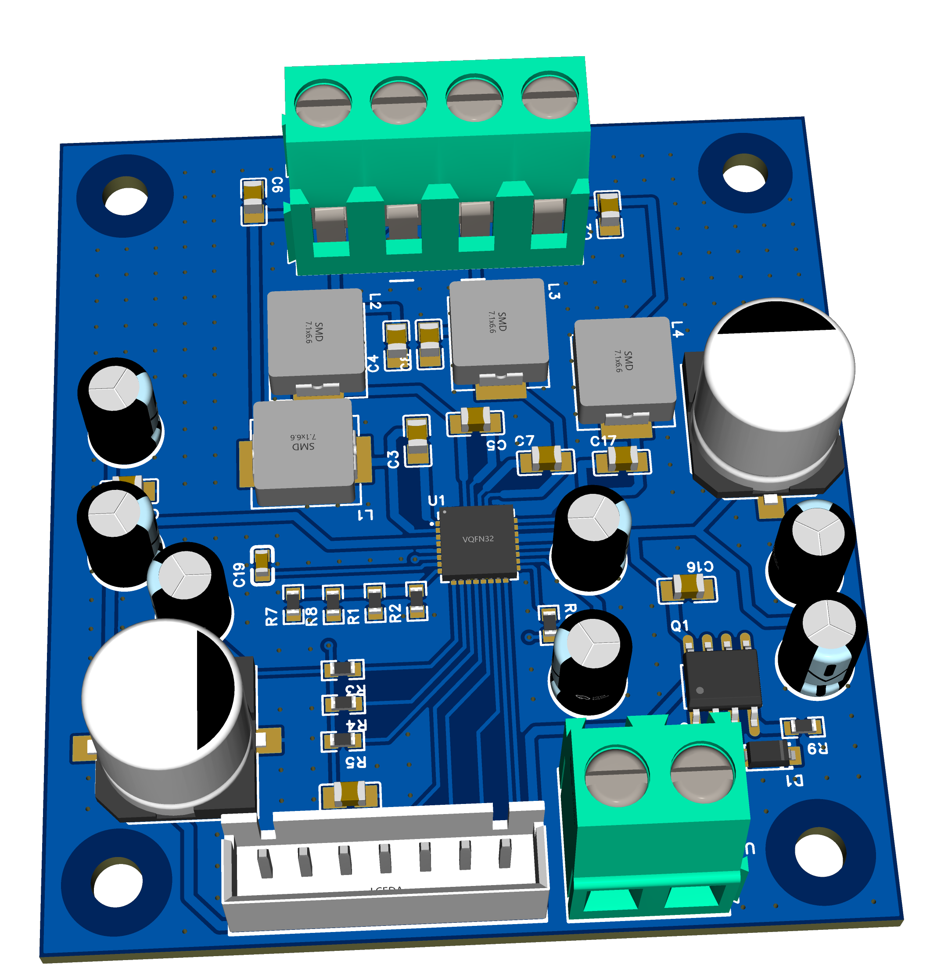
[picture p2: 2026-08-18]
docs/PortaDome3D.png

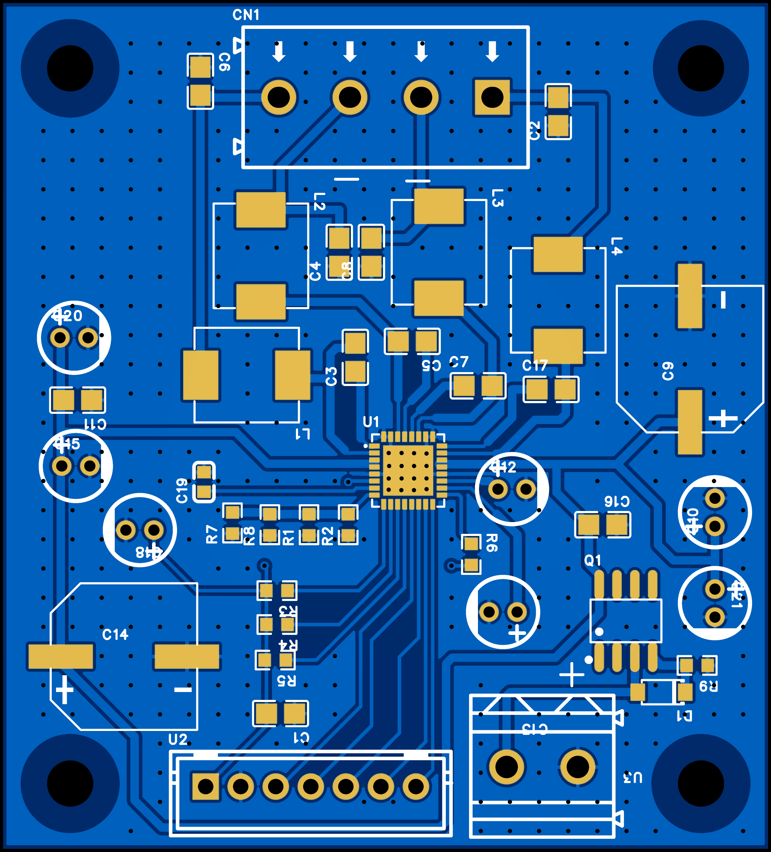
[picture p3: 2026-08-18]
docs/PortaDome2D.png

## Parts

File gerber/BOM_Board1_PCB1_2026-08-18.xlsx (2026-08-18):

No. | Quantity | Comment | Designator | Footprint | Value | Manufacturer Part | Manufacturer | Supplier Part | Supplier
1 | 2 | 100nF | C1,C11 | C0805 | 100nF | AC0805KKX7R9BB474 | YAGEO(国巨) |  | LCSC
2 | 4 | 680nF | C2,C4,C6,C8 | C0805 | 680nF | 0805X7R474K250NT | AIDE(爱迪电容) |  | LCSC
3 | 1 | 470nF | C3 | C0805 | 470nF | 0805X7R474K250NT | AIDE(爱迪电容) |  | LCSC
4 | 3 | 470nF | C5,C7,C17 | C0805 | 470nF | 0805X7R474K250NT | AIDE(爱迪电容) | C48579644 | LCSC
5 | 2 | 390uF | C9,C14 | CAP-SMD_BD10.0-L10.3-W10.3-FD | 390uF | BXJ 35V390 10*10 | SAMYOUNG(韩国三莹) | C359223 | LCSC
6 | 7 | 22uF | C10,C12,C13,C15,C18,C20,C21 | CAP-TH_BD5.0-P2.00-D0.8-FD | 22uF | GR226M050D11RR0VH4FP0 | Chengx(承兴) | C28057 | LCSC
7 | 1 | 100nF | C16 | C0805 | 100nF | 0805X7R474K250NT | AIDE(爱迪电容) |  | LCSC
8 | 1 | 1µF | C19 | C0603 | 1µF
9 | 1 | DB128L-5.08-4P-GN-S | CN1 | CONN-TH_4P_DB128L-5.08-4P-GN-S |  | DB128L-5.08-4P-GN-S | DORABO(地博电气) | C2827883 | LCSC
10 | 1 | MM1Z15 | D1 | SOD-123_L2.8-W1.8-LS3.7-RD |  | MM1Z15 | 晶导微电子 | C115219 | LCSC
11 | 4 | 10uH | L1,L2,L3,L4 | IND-SMD_L7.3-W6.6 | 10uH | MHCI06024-100M-R8A | Chilisin(奇力新) | C280584 | LCSC
12 | 1 | AO4407A | Q1 | SOIC-8_L4.9-W3.9-P1.27-LS6.0-BL |  | AO4407A | AOS | C16072 | LCSC
13 | 1 | 1K | R1 | R0603 | 1K
14 | 1 | 15K | R2 | R0603 | 15K
15 | 4 | 10K | R3,R4,R5,R6 | R0603 | 10K
16 | 1 | 4.7K | R7 | R0603 | 4.7K
17 | 1 | 0 | R8 | R0603 | 0
18 | 1 | 100K | R9 | R0603 | 100K
19 | 1 | TAS5825MRHBR | U1 | VQFN-32_L5.0-W5.0-P0.50-TL-EP |  | TAS5825MRHBR | TI(德州仪器) | C471049 | LCSC
20 | 1 | B7B-XH-A(LF)(SN) | U2 | CONN-TH_7P-P2.50_B7B-XH-A-LF-SN |  | B7B-XH-A(LF)(SN) | JST | C144398 | LCSC
21 | 1 | DB128L-5.08-2P-GN-S | U3 | CONN-TH_2P-P5.08_DB128L-5.08-2P |  | DB128L-5.08-2P-GN-S | DORABO(地博电气) | C395868 | LCSC

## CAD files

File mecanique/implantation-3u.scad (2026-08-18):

// =============================================================================
// PortaDome — implantation du coffret 3U
// =============================================================================
//
// But : repondre a « est-ce que ca rentre », et surtout determiner la taille
// que la carte ampli peut avoir. Ce ne sont que des volumes d'encombrement,
// pas des modeles reels — pour les collisions fines, passer par FreeCAD avec
// les STEP d'EasyEDA, Mean Well et Neutrik.
//
// UTILISATION : F5 pour l'apercu (F6 = rendu final, inutile ici et lent).
// Si la vue est vide : View > View All pour recadrer, le modele fait 450 mm.
// Les echo() en bas verifient les degagements et affichent OK ou DEPASSE
// dans la console. Change une cote, relance F5, lis la console.
//
// Voir docs/mecanique-coffret.md
// =============================================================================


/* [Carte ampli — LA variable de l'etude] */

// Longueur, dans le sens de la profondeur du rack (54.6 = carte actuelle)
carte_long      = 54.6;
// Hauteur, du connecteur en bas au bord superieur (60.3 = carte actuelle)
carte_haut      = 60.3;
// Enveloppe en epaisseur : PCB + composants les plus hauts (selfs ~4mm, condos ~10mm)
carte_ep        = 12;
// Pas entre cartes — contraint par la ventilation, ne pas descendre sous 20
carte_pas       = 20;
// Cartes par carte mere
cartes_par_mere = 4;


/* [Rack 3U] */

rack_u          = 3;
rack_larg_utile = 450;   // entre montants
rack_prof       = 300;   // profondeur interne, au choix
tole            = 2;     // epaisseur des toles


/* [Carte mere] */

mere_larg_marge = 10;    // marge de chaque cote des cartes enfichees
mere_prof       = 80;
mere_ep         = 1.6;
mere_z          = 12;    // hauteur des entretoises sous la carte mere
mere_nb         = 3;
mere_ecart      = 12;    // espace entre deux cartes meres

connecteur_h    = 11;    // hauteur du couple embase male + femelle accouple


/* [Carte MCU] */

mcu_larg        = 100;
mcu_prof        = 80;


/* [Alimentation — Mean Well UHP-350-24] */

alim_long       = 220;
alim_larg       = 62;
alim_haut       = 31;


/* [Ventilation] */

vent_dia        = 120;
vent_ep         = 25;
vent_nb         = 2;      // soufflants en facade
vent_arr_nb     = 1;      // extracteurs en face arriere (push-pull)
vent_arr_dia    = 120;


/* [Speakon NL4 — face arriere] */

// ATTENTION : cutout 24mm et vis M3 confirmes. L'entraxe ci-dessous est une
// ESTIMATION — le prendre dans le DXF Neutrik avant de percer quoi que ce soit.
spk_cutout      = 24;
spk_pas         = 34;    // <<< A CONFIRMER SUR DXF NEUTRIK
spk_nb          = 13;
spk_rangees     = 2;
spk_ecart_rang  = 45;
// Decale sur la gauche pour liberer la place de l'extracteur a droite.
spk_marge_g     = 20;


/* [Affichage] */

montrer_rack    = true;
montrer_cartes  = true;
montrer_alim    = true;
montrer_vent    = true;
montrer_panneau = true;
eclate          = 0;     // ecarte les blocs en Z pour y voir clair


// =============================================================================
// Valeurs derivees
// =============================================================================

rack_haut    = rack_u * 44.45;
rack_h_utile = rack_haut - 2 * tole;

mere_larg    = cartes_par_mere * carte_pas + 2 * mere_larg_marge;
meres_larg   = mere_nb * mere_larg + (mere_nb - 1) * mere_ecart;
larg_totale  = meres_larg + mere_ecart + mcu_larg;

// hauteur du sommet de la carte ampli au-dessus du plancher
pile_haut    = mere_z + mere_ep + connecteur_h + carte_haut;

// profondeur occupee par une rangee carte mere + alim derriere
prof_occupee = mere_prof + 20 + alim_larg;

spk_par_rang = ceil(spk_nb / spk_rangees);
spk_larg     = spk_par_rang * spk_pas;

vent_larg    = vent_nb * vent_dia;


// =============================================================================
// Modules
// =============================================================================

module carte_ampli() {
    color("SeaGreen")
        cube([carte_ep, carte_long, carte_haut]);
}

module bloc_mere() {
    // la carte mere elle-meme
    color("DarkSlateBlue")
        translate([0, 0, mere_z])
            cube([mere_larg, mere_prof, mere_ep]);

    // les cartes ampli debout dessus
    if (montrer_cartes)
        for (i = [0 : cartes_par_mere - 1])
            translate([mere_larg_marge + i * carte_pas + (carte_pas - carte_ep) / 2,
                       (mere_prof - carte_long) / 2,
                       mere_z + mere_ep + connecteur_h])
                carte_ampli();

    // le volume des connecteurs, pour voir la place qu'ils prennent
    color("Goldenrod")
        for (i = [0 : cartes_par_mere - 1])
            translate([mere_larg_marge + i * carte_pas + (carte_pas - carte_ep) / 2,
                       (mere_prof - carte_long) / 2,
                       mere_z + mere_ep])
                cube([carte_ep, carte_long, connecteur_h]);
}

module bloc_mcu() {
    color("DarkSlateBlue")
        translate([0, 0, mere_z])
            cube([mcu_larg, mcu_prof, mere_ep]);

    // 1 carte ampli (le sub) + volume Teensy
    if (montrer_cartes) {
        translate([mere_larg_marge, (mcu_prof - carte_long) / 2,
                   mere_z + mere_ep + connecteur_h])
            carte_ampli();

        color("Firebrick")
            translate([mcu_larg - 70, 10, mere_z + mere_ep])
                cube([61, 18, 8]);   // Teensy 4.1
    }
}

module bloc_alim() {
    color("Silver")
        cube([alim_long, alim_larg, alim_haut]);
}

module ventilateur() {
    color("DimGray")
        rotate([-90, 0, 0])
            difference() {
                translate([-vent_dia/2, -vent_dia/2, 0])
                    cube([vent_dia, vent_dia, vent_ep]);
                translate([0, 0, -1]) cylinder(d = vent_dia - 8, h = vent_ep + 2, $fn = 64);
            }
}

module panneau_arriere() {
    color("Gainsboro")
        difference() {
            cube([rack_larg_utile, tole, rack_h_utile]);

            // les cutouts Speakon
            for (r = [0 : spk_rangees - 1])
                for (i = [0 : spk_par_rang - 1])
                    if (r * spk_par_rang + i < spk_nb)
                        translate([spk_marge_g + spk_pas/2 + i * spk_pas,
                                   -1,
                                   rack_h_utile/2 - (spk_rangees-1)*spk_ecart_rang/2 + r * spk_ecart_rang])
                            rotate([-90, 0, 0])
                                cylinder(d = spk_cutout, h = tole + 2, $fn = 32);

            // decoupe du ou des extracteurs, a droite du bloc Speakon
            for (v = [0 : vent_arr_nb - 1])
                translate([rack_larg_utile - (vent_arr_nb - v) * vent_arr_dia + vent_arr_dia/2 - 10,
                           -1, rack_h_utile/2])
                    rotate([-90, 0, 0])
                        cylinder(d = vent_arr_dia - 8, h = tole + 2, $fn = 48);
        }
}

// Enveloppe en fil de fer : une boite transparente s'affiche tres mal en
// apercu OpenSCAD (ordre de rendu imprevisible) et masque tout le contenu.
module enveloppe_rack(e = 3) {
    L = rack_larg_utile; P = rack_prof; H = rack_h_utile;
    color("SteelBlue")
    union() {
        // 4 montants verticaux
        for (x = [0, L - e], y = [0, P - e])
            translate([x, y, 0]) cube([e, e, H]);
        // 4 traverses en largeur (bas et haut)
        for (y = [0, P - e], z = [0, H - e])
            translate([0, y, z]) cube([L, e, e]);
        // 4 traverses en profondeur (bas et haut)
        for (x = [0, L - e], z = [0, H - e])
            translate([x, 0, z]) cube([e, P, e]);
    }
}


// =============================================================================
// Assemblage
// =============================================================================

if (montrer_rack) enveloppe_rack();

// les 3 cartes meres, alignees a l'avant derriere les ventilateurs
for (m = [0 : mere_nb - 1])
    translate([m * (mere_larg + mere_ecart), vent_ep + 15, 0])
        bloc_mere();

// la carte MCU a droite
translate([meres_larg + mere_ecart, vent_ep + 15, 0])
    bloc_mcu();

// l'alimentation, derriere, en aval du flux
if (montrer_alim)
    translate([(rack_larg_utile - alim_long) / 2,
               vent_ep + 15 + mere_prof + 20,
               eclate])
        bloc_alim();

// les ventilateurs en facade
if (montrer_vent)
    for (v = [0 : vent_nb - 1])
        translate([(rack_larg_utile - vent_larg) / 2 + vent_dia/2 + v * vent_dia,
                   0,
                   rack_h_utile / 2])
            ventilateur();

if (montrer_panneau)
    translate([0, rack_prof, 0]) panneau_arriere();

// extracteurs en face arriere (push-pull)
if (montrer_vent)
    for (v = [0 : vent_arr_nb - 1])
        translate([rack_larg_utile - (vent_arr_nb - v) * vent_arr_dia + vent_arr_dia/2 - 10,
                   rack_prof - vent_ep, rack_h_utile / 2])
            ventilateur();
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

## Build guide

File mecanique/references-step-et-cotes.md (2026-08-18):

# Modèles STEP et cotes de référence

> Document de travail pour l'assemblage FreeCAD du coffret 3U.
> Voir [`../docs/mecanique-coffret.md`](../docs/mecanique-coffret.md) pour les décisions,
> et [`implantation-3u.scad`](./implantation-3u.scad) pour l'étude d'encombrement paramétrique.
>
> ⚠️ **Statut des cotes** : ce document distingue explicitement ce qui a été **vérifié** de ce qui
> reste **estimé**. Ne pas percer, commander ou router sur une cote estimée.

## 1. Modèles STEP à récupérer

| Pièce | Où | Notes |
|---|---|---|
| **Carte ampli** | Export depuis EasyEDA Pro | `Fichier → Exporter → STEP` (ou 3D). Donne le contour, les composants et leurs hauteurs réelles — c'est la pièce la plus importante de la liste. |
| **Carte mère** | À créer | N'existe pas encore. En attendant, une plaque de 100 × 80 × 1,6 mm suffit à réserver le volume. |
| **Speakon NL4MP** | [neutrik.com](https://www.neutrik.com/en/product/nl4mp) → onglet Downloads | Neutrik publie **STEP et DXF**. Le DXF donne le gabarit de perçage du panneau, le STEP le volume de la fiche accouplée. **Prendre les deux.** |
| **Mean Well UHP-350-24** | [meanwell.com](https://www.meanwell.com) → fiche produit → section Download | Mean Well fournit les 3D. Récupérer aussi le plan coté pour les trous de fixation. |
| **Embases 2,54 mm** (2×4 et 2×8) | Site du fabricant (Wurth, Samtec, Harwin), ou SnapEDA / Ultra Librarian / ComponentSearchEngine | Prendre le **couple accouplé** mâle + femelle, pas seulement l'embase : c'est la hauteur accouplée qui compte pour la pile. |
| **Ventilateur 120 mm** | Noctua et Arctic publient des STEP | Un cube de 120 × 120 × 25 mm suffit pour l'encombrement ; le STEP réel sert surtout pour les trous de fixation. |
| **Châssis rack 19" 3U** | Hammond, Schroff, Rittal — tous publient des STEP | Décider d'abord si le châssis est acheté ou fabriqué. S'il est acheté, son STEP devient la référence de tout l'assemblage. |
| **Teensy 4.1** | GrabCAD, ou cotes PJRC | Modèles communautaires. Contour officiel : 61 × 18 mm. |
| **Entretoises et visserie** | [mcmaster.com](https://www.mcmaster.com) | Chaque référence a son STEP téléchargeable. C'est la source la plus rapide pour la visserie. Alternative : TraceParts. |
| **Entrée secteur CEI** | Schurter publie des STEP | Choisir le modèle (avec ou sans porte-fusible et interrupteur) avant de dessiner le panneau. |

## 2. Cotes vérifiées

Ces valeurs ont été relevées sur les fichiers de fabrication ou les fiches constructeur.

### Carte ampli (état 2026-08-18, avant refonte)

| Cote | Valeur | Source |
|---|---|---|
| Contour | **54,610 × 60,325 mm** | mesuré sur `Gerber_BoardOutlineLayer.GKO` |
| Trous de fixation | **4 × Ø 3,30 mm** | `Drill_NPTH_Through.DRL`, outil unique |
| Entraxe | **45,000 × 51,000 mm** | idem |
| Positions (depuis coin bas-gauche) | (4,805 / 55,662) · (49,805 / 55,662) · (4,805 / 4,662) · (49,805 / 4,662) | idem |
| Marges au bord | 4,805 mm gauche/droite · 4,66 mm haut/bas | calculé |

⚠️ Ces cotes valent pour la carte **actuelle**. La refonte peut les changer — mais l'implantation a
établi que **le rack ne contraint ni la longueur ni la hauteur** (jusqu'à 152 et 80 mm).

### Rack

| Cote | Valeur |
|---|---|
| 1 U | 44,45 mm |
| 3 U | 133,35 mm |
| Largeur panneau 19" | 482,6 mm |
| Largeur interne utile | ~450 mm |

### Alimentation Mean Well UHP-350-24

| Cote | Valeur |
|---|---|
| Encombrement | **220 × 62 × 31 mm** |
| Puissance | 350 W, 24 V, 14,6 A |
| Refroidissement | **convection, sans ventilateur** |
| Rendement | 94 % |

### Speakon Neutrik, série D

| Cote | Valeur |
|---|---|
| Perçage panneau | **24 mm** (23,8 mm) |
| Vis de fixation | **M3**, 2 par connecteur |

## 3. Cotes à vérifier avant de figer quoi que ce soit

| Cote | Pourquoi elle compte | Où la prendre |
|---|---|---|
| **Composant le plus haut de la carte ampli** | ⚠️ **La plus critique.** Elle fixe l'enveloppe en épaisseur, donc le canal d'air entre cartes — aujourd'hui estimé à 8 mm seulement. Estimation actuelle : condensateurs 390 µF à ~10,3 mm (d'après l'empreinte `CAP-SMD_BD10.0-L10.3-W10.3`). | STEP EasyEDA, ou fiche du condensateur et de la self |
| **Hauteur des selfs** Chilisin MHCI06024 | Deuxième composant le plus haut, potentiellement limitant | fiche Chilisin (`C280584`) |
| **Largeur de bride et entraxe mini des NL4** | Décide entre 1 rangée de 13 et 2 rangées de 7 sur le panneau. Estimation actuelle : 34 mm de pas | DXF Neutrik |
| **Hauteur accouplée des embases 2,54 mm** | Entre dans la hauteur de pile. Estimation actuelle : 11 mm | fiche du connecteur retenu |
| **Trous de fixation de l'alimentation** | Position et filetage | plan coté Mean Well |
| **Profondeur réelle du châssis** | Aujourd'hui prise à 300 mm arbitrairement, avec 98 mm inutilisés | catalogue du châssis retenu |

## 4. Vérifications à faire une fois assemblé dans FreeCAD

Ce que le modèle de volumes ne peut pas dire, et que l'assemblage réel dira :

1. **Canal d'air réel entre deux cartes ampli voisines.** C'est la contrainte identifiée : au pas de
   20 mm avec une enveloppe de ~12 mm, il ne reste que 8 mm. Mesurer entre les composants les plus
   hauts de deux cartes adjacentes, pas entre les PCB.
2. **Collision connecteur ↔ entretoises** sous les cartes mères.
3. **Dégagement des fiches Speakon accouplées** en face arrière — le corps de la fiche câble est
   nettement plus gros que le connecteur panneau, et c'est lui qui borne l'entraxe utilisable.
4. **Rayon de courbure des 25 câbles HP** en sortie de panneau, et leur maintien mécanique.
5. **Chemin d'air** : vérifier qu'aucun volume ne fait écran entre les ventilateurs et les cartes,
   et que l'alimentation est bien en aval.
6. **Accès à l'extraction d'une carte ampli** : peut-on la sortir sans outil et sans démonter autre
   chose ? C'est tout l'intérêt du format debout, et c'est le genre de chose qui ne se voit qu'en 3D.
7. **Longueurs d'entretoises** : les déduire de l'assemblage plutôt que de les choisir a priori.
8. **Accès au câblage secteur** et distance de sécurité par rapport aux cartes.

## 5. Ordre suggéré

1. **Exporter la carte ampli en STEP** depuis EasyEDA — c'est la pièce qui débloque le reste, et
   elle donne la hauteur du composant le plus haut, la cote la plus critique de la liste §3.
2. **Choisir le châssis** (acheté ou fabriqué). Son STEP devient la référence de l'assemblage.
3. Importer alimentation, Speakon, ventilateurs.
4. Placer, puis dérouler les vérifications du §4.
5. **Reporter dans `docs/mecanique-coffret.md`** toute cote que l'assemblage tranche — en
   particulier la §8 « ce qui reste à coter ».

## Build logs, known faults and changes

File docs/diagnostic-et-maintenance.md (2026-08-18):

# Diagnostic et maintenance

> Créé le 2026-08-18. Comment savoir **rapidement ce qui se passe** sur 13 modules et 25 voies,
> depuis un client sur l'ordinateur relié en USB.
>
> Registres relevés dans le datasheet TAS5825M §9.5.3.3 et §9.6 (Table 9-6).

## 1. Pourquoi c'est jouable

Trois décisions prises le 18/08 rendent le diagnostic possible sans matériel supplémentaire :

1. **FAULTZ et WARNZ routés au connecteur**, câblés en OU par carte mère — une broche MCU pour
   quatre amplis.
2. **Adressage I2C par slot** — la Teensy sait quelle puce est physiquement où.
3. **La Teensy est déjà maître I2C** de toutes les puces, via le multiplexeur.

Il ne manque donc que du firmware et un client.

## 2. Ce que la puce sait dire d'elle-même

Le TAS5825M est bien mieux instrumenté qu'un ampli analogique. Registres utiles, relevés dans la
Table 9-6 :

| Registre | Nom | Ce qu'il apporte au diagnostic |
|---|---|---|
| `5Eh` | `PVDD_ADC` | ⭐ **La puce mesure sa propre alimentation.** Avec 13 puces, on obtient **13 points de mesure du rail 24 V** répartis dans le rack — un voltmètre distribué gratuit, qui localise une chute de tension dans la distribution. |
| `38h` | `BCK (SCLK)_MON` | La fréquence d'horloge **réellement vue** par cette puce |
| `37h` | `FS_MON` | La fréquence d'échantillonnage vue par cette puce |
| `39h` | `CLKDET_STATUS` | Détection d'erreur d'horloge |
| `68h` | `POWER_STATE` | État courant (deep sleep / HiZ / play) |
| `67h` | `DIE_ID` | **Test de présence** : si elle répond, le module est vivant sur I2C |
| `4Ch` | `DIG_VOL` | Volume numérique appliqué |
| `50h` | `AUTO_MUTE_CTRL` | Mise en sourdine automatique |

**Les deux registres qui changent tout** :

- **`PVDD_ADC`** transforme un problème d'alimentation diffus (« ça sature en bout de dôme ») en une
  mesure par module. Si la carte mère 3 lit 22,1 V pendant que la 1 lit 23,9 V, la chute dans la
  distribution est chiffrée, pas supposée.
- **`BCK_MON` / `FS_MON`** répondent à la question qui reviendra le plus souvent : *« le module 7
  est muet — est-ce l'audio ou l'horloge ? »* Si la puce voit son horloge, le problème est en aval.

## 3. Les protections et ce qu'elles signalent

D'après §9.5.3.3 :

| Événement | Comportement | Signalé par |
|---|---|---|
| **OCSD** — court-circuit franc | Coupe le canal en **< 100 ns**. Redémarrage possible par I2C. | broche FAULT + registre de défaut |
| **DC Detect** — offset continu en sortie | **FAULTZ passe bas**, sorties en haute impédance | FAULTZ |
| **CBC** — limitation cycle par cycle | Écrête proprement les crêtes, reprise normale à la disparition de la surcharge | transparent |
| **Repli thermique** | Réduit la puissance avant de couper | WARNZ |

⚠️ **Note importante pour la carte sub** : le datasheet précise que **la limitation CBC n'existe
qu'en BTL, pas en PBTL**. Le caisson perd donc la limitation douce et ne garde que l'OCSD, qui coupe
brutalement. Un court-circuit sur le câble du caisson provoquera un arrêt franc là où une voie
normale se contenterait d'écrêter.

## 4. La séquence de démarrage, et pourquoi PDN compte

Le datasheet §9.5.3.1 impose un ordre :

1. Configurer ADR
2. Monter les alimentations (PVDD ou DVDD, l'ordre est indifférent)
3. **PDN à l'état haut, attendre ≥ 5 ms, puis démarrer SCLK et LRCLK**
4. Mettre en HiZ et activer le DSP par I2C
5. Attendre 5 ms, charger les coefficients DSP, passer en Play

C'est la justification concrète du routage de PDN : **la Teensy peut redémarrer proprement un module
sans couper le 24 V de toute la carte mère**. Extinction par le registre `03h` D[1:0]=10 (HiZ) ou par
PDN bas.

Sans PDN piloté, la seule façon de sortir une puce d'un état bloqué serait de couper l'alimentation
des quatre cartes du même slot.

## 5. Le client USB

La Teensy 4.1 peut présenter **plusieurs classes USB simultanément** — le même câble transporte donc
l'audio *et* la télémétrie, sans connexion supplémentaire. *(À confirmer dans les types USB de
Teensyduino au moment du firmware.)*

**Ce que le client devrait montrer**, par ordre d'utilité :

- **Une grille de 13 modules × 2 voies.** Chaque module : présent/absent, défaut, alerte, PVDD lu,
  horloge vue. Un module en défaut se voit sans lire un chiffre.
- **Le rail 24 V par module**, puisqu'on l'a gratuitement. C'est la mesure qui trahit un problème de
  distribution avant qu'il ne devienne audible.
- **Un journal horodaté** des événements. Sur une installation qui tourne, savoir *quand* le module
  7 a fauté vaut mieux que savoir qu'il a fauté.
- **Le niveau par voie**, pour vérifier d'un coup d'œil que les 25 voies reçoivent bien du signal —
  c'est le test qui distingue un problème de routage des slots TDM d'un problème matériel.

**Le protocole n'a pas besoin d'être sophistiqué** : du texte sur le port série USB suffit, et reste
lisible dans un terminal si le client n'est pas lancé. Ne pas inventer un format binaire avant d'en
avoir le besoin.

## 6. Le client sert aussi à régler le filtrage

Le TAS5825M porte **15 biquads par voie**, plus DRC et AGL. Sur un dôme, l'égalisation dépend de la
position de chaque haut-parleur — c'est précisément ce que la spec §7 attend du DSP intégré. Le
client n'est donc pas seulement un moniteur : c'est l'outil de réglage.

### Ne pas recalculer ce que TI calcule déjà

TI fournit **PPC3** (PurePath Console 3), qui conçoit les filtres et **exporte le jeu de
coefficients**. Le datasheet §10.2.3.2 décrit ce flux comme la voie normale. Il ne faut donc pas
écrire un calculateur de biquads : on conçoit dans PPC3, on exporte, et **le client se charge de
pousser les coefficients vers la bonne puce**.
*(À vérifier : PPC3 fonctionne-t-il sans l'EVM de TI branché ?)*

Ce que PPC3 ne sait pas faire et que le client doit apporter : viser **une puce parmi treize**, à
travers la Teensy et le multiplexeur, et régler **en écoutant**, en se déplaçant dans le dôme.

### L'architecture qui découle : la Teensy reste bête

Le client ne parle jamais I2C directement — il demande à la Teensy de le faire.

```
Client (ordinateur)  ──USB série──►  Teensy  ──I2C via mux──►  13 × TAS5825M
   toute l'intelligence              simple relais
```

Le protocole se réduit à trois opérations : **lire un registre**, **écrire un registre**, **et
diffuser la télémétrie**, chacune adressée par numéro de module. Rien de plus.

Le bénéfice est décisif au quotidien : **on itère sur le client sans jamais reflasher la Teensy**.
Sur un an de réglages, c'est la différence entre une boucle de cinq secondes et une de deux minutes.

### Où vivent les coefficients

Trois options, par ordre de préférence :

1. **Fichier sur la carte SD de la Teensy** — un jeu par position dans le dôme, éditable
   centralement, rechargeable sans recompiler. **Recommandé.**
2. Compilés dans le firmware — impose une recompilation à chaque retouche de réglage.
3. EEPROM externe par puce — le TAS5825M sait démarrer sur une EEPROM (registres `56h`-`5Bh`,
   Table 9-6). Élégant mais dispersé : treize mémoires à maintenir au lieu d'un fichier.

### Construire par couches

- **Couche 1 — télémétrie en lecture seule.** Nécessaire de toute façon pour la mise en service,
  et sans risque : on ne peut rien casser en lisant.
- **Couche 2 — écriture de registres.** Volume, mute, PDN, redémarrage d'un module.
- **Couche 3 — coefficients DSP.** Le réglage du dôme proprement dit.

La couche 1 peut démarrer aujourd'hui : elle ne dépend d'aucun choix matériel restant.

## 7. Le déroulé d'un dépannage

1. **Un voyant s'allume** — FAULTZ ou WARNZ d'une carte mère passe bas. Le MCU sait sur quelle carte
   mère, pas sur quelle puce (les lignes sont câblées en OU).
2. **Le MCU interroge les 4 puces** de cette carte mère et lit leurs registres de défaut. Il sait
   maintenant laquelle et pourquoi.
3. **Le client affiche** le module, la nature du défaut, et son historique.
4. **Redémarrage à distance** par PDN ou par I2C, sans toucher au rack.
5. Si le défaut persiste : **la carte se remplace en la débrochant**, sans outil et sans dévisser
   quoi que ce soit — c'est la raison d'être du format debout. Les cartes étant identiques et
   adressées par leur slot, une carte de rechange se met à n'importe quelle place.
6. La carte suspecte part sur la **carte d'adaptation** au banc, où on l'examine une voie à la fois.

## 8. À faire

- [ ] Confirmer les types USB combinés de la Teensy 4.1 (audio + série)
- [ ] Vérifier si PPC3 fonctionne sans l'EVM TI branché
- [ ] Définir le protocole série : lire registre / écrire registre / télémétrie, adressés par module
- [ ] Relever les registres de défaut au-delà de `68h` — la Table 9-6 se poursuit page 45
- [ ] Vérifier si une **lecture de température de puce** existe dans le reste de la table
- [ ] Écrire la couche de lecture I2C (indépendante du matériel, peut démarrer maintenant)
- [ ] Définir le format de télémétrie sur le port série

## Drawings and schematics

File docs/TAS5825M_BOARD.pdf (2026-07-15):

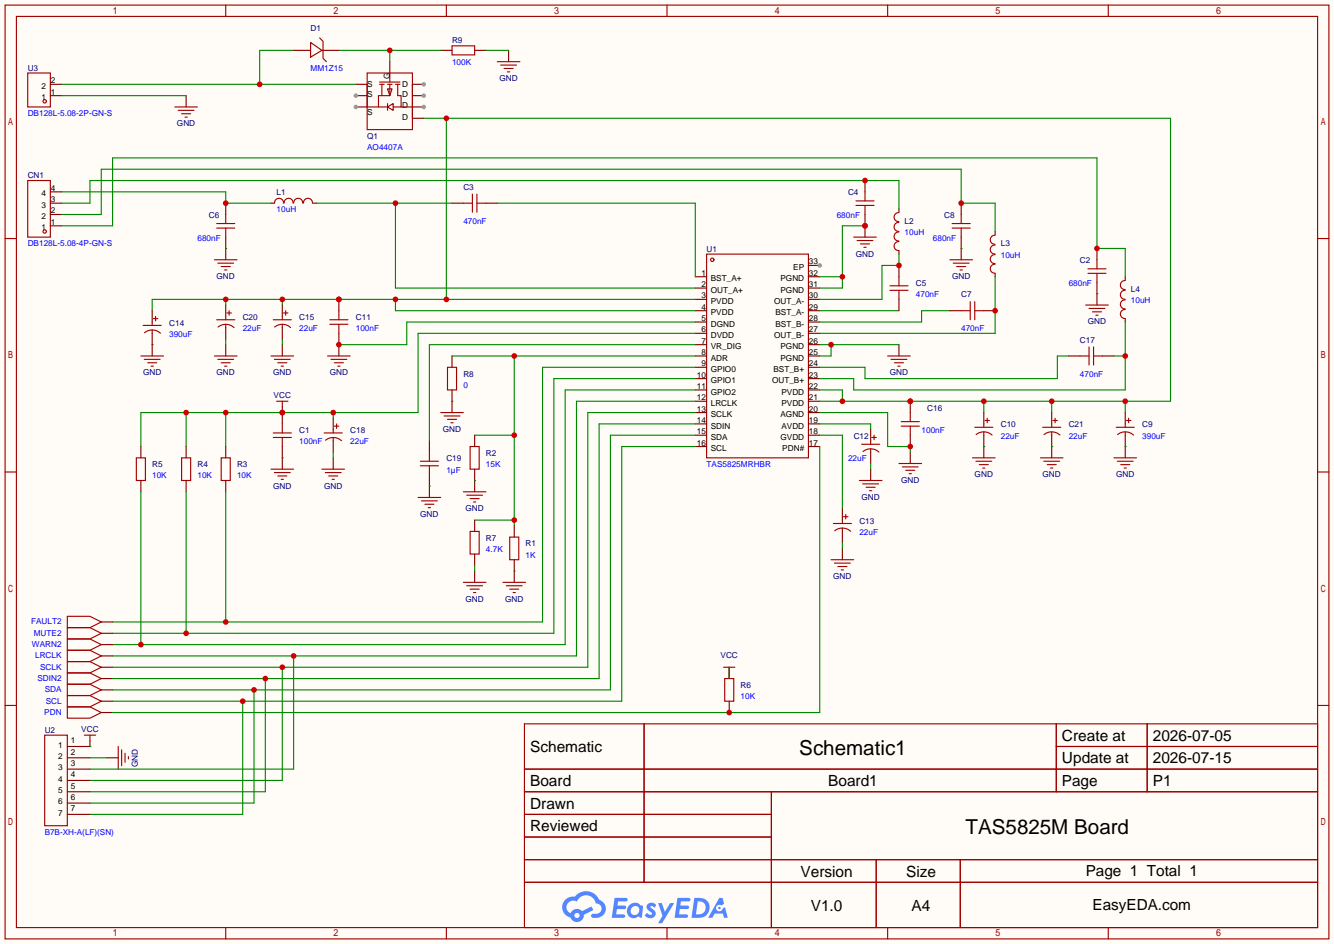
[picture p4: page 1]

Schematic | Schematic1 | Create at | 2026-07-05

Update at | 2026-07-15

Board | Board1 | Page | P1
Drawn | | TAS5825M Board
Reviewed

Version | Size | Page 1 Total 1
V1.0 | A4 | EasyEDA.com

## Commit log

2026-07-04 Prologue
    04/07/26
    J'ai en mais la teensy 3.6.
    J'ai téléchargé l'application Arduino IDE et le VS Code.
    Pour l'instant j'utilise Gemini comme assistant IA.
2026-07-04 Phase 0
    J'ai réussi à faire la teensy clignoter à l'interval de 1s, puis je l'ai changé vers 500ms, puis je l'ai éteint.
    Suit à ça je me suis informé sur le fonctionnement de github et comment faire un commit.
    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
2026-07-04 Phase 1 (premier test)
    J'ai ajouté un code de manière à ce que la teensy puisse lire un fichier audio depuis une carte sd sur reaper.
    Finalement je n'ai eu aucun son sur reaper.
2026-07-05 Phase 1 deuxième test
    rien que avec du code, j'ai réussi à faire jouer un fichier stereo depuis la teensy. je vais m'en servir de l'audio design tool pour comprendre comment ça marche
2026-07-05 Phase 1 (troisième test)
    j'ai utilisé l'audio library pour créer le flux audio en récupérant ce qui venait de la carte sd en sortant par le port usb. finalement ça fait la même chose que ce que j'avait codé mais avec des nom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
2026-07-05 Documentation : specs projet + proto ampli TAS5825M
    Ajoute la feuille de route et la spec technique du dome (docs/), et
    documente le plan de prototype ampli mono-puce TAS5825M (BOM, cablage
    XIAO ESP32-S3, plan de fabrication, points a verifier avant PCB final).
2026-07-05 Ajoute schemas de reference et corrige bootstrap/ADR via datasheet
    Sauvegarde les schemas Esparagus et BassOwl-HAT + le datasheet TAS5825M
    dans docs/refs/. La verification contre le datasheet officiel corrige
    une erreur de lecture du schema Esparagus : les condensateurs 470nF
    sont les bootstrap caps obligatoires (BST_x <-> OUT_x), pas un filtre.
    Confirme aussi la table resistance ADR -> adresse I2C (Table 9-5).
2026-07-05 Ajoute pinout XIAO S3, ref LCSC puce et self de sortie
    Documente le mapping GPIO XIAO ESP32-S3 retenu pour BCLK/WS/DATA/SDA/SCL
    (verifie contre le pinout officiel Seeed). Ajoute les references LCSC
    pour le TAS5825MRHBR (C471049, VQFN-32 5x5mm confirme) et pour la self
    de sortie 10uH (Chilisin MHCI06024-100M-R8A, C280584, 4A, en stock).
    Met a jour l'estimation de cout JLCPCB avec le prix reel du composant.
2026-07-05 Ajoute connecteur JST-XH detrompe et regle du pont de soudure ADR
    Documente le connecteur U2 (JST-XH B7B-XH-A, 7 positions) qui relie la
    carte au XIAO S3, avec son brochage exact (VCC, GND, BCLK, WS, SDIN,
    SDA, SCL) et le boitier XHP-7 assorti cote cable. Ajoute un
    avertissement pour le layout PCB : les 4 resistances ADR doivent
    chacune avoir un pont de soudure ouvert par defaut, pas une piste
    continue, sinon la resistance 0 ohm ecrase les 3 autres adresses.
2026-07-05 Ajoute le schema final valide et la protection anti-inversion
    Sauvegarde l'export du schema EasyEDA (TAS5825M_BOARD.pdf), relu et
    corrige au fil de l'eau (bootstrap, ADR, GPIO XIAO, connecteur JST-XH,
    protection anti-inversion). Documente le circuit de protection
    (U3 bornier alim, Q1 MOSFET P-channel, D1 zener, R9 100k) dans la BOM.
2026-07-10 Marque le placement/routage PCB comme termine
    DRC propre (connexions + clearance). Alerte netlist mismatch
    non-bloquante laissee de cote, cause identifiee (nets assignes a la
    main sur des vias en PCB plutot que dans le schema).
2026-07-15 Documente les valeurs de condensateurs verifiees et ajoute les fichiers de fab
    Liste complete des 21 condensateurs (C1-C21) relue depuis le schema
    final, avec net et tension recommandee par composant. Corrige C9/C14 :
    390uF sur PVDD (24V), necessite 35-50V, boitier electrolytique
    nettement plus gros que prevu au layout initial (rework PCB en cours).
    Ajoute les fichiers de fabrication generes (Gerber, BOM, PickAndPlace)
    du premier passage de devis JLCPCB.
    [BOM_Board1_PCB1_2026-07-11.xlsx, PickAndPlace_PCB1_2026_07_11.xlsx]
2026-07-15 Change de plan : assemblage JLCPCB complet plutot que U1 seul
    Devis reel obtenu : PCB nu 5.35$, assemblage complet + envoi 102$
    pour 5 cartes (inclut 28$ de frais "Extended Components"). Reste a
    calculer le cout avec seulement U1 assemble pour comparer avant de
    valider le choix definitif.
2026-07-15 Documente la comparaison de cout assemblage complet vs U1 seul
    Estimation : ~60-85$ pour U1 seul assemble (JLCPCB + achats LCSC
    separes) contre 102$ tout compris pour l'assemblage complet retenu.
    Ajoute la comparaison avec une carte du commerce (Louder ESP32 Plus) :
    notre cout par carte est coherent avec le marche pour un circuit ampli
    equivalent, une fois l'ESP32 non-necessaire retire du prix Sonocotta.
2026-07-15 Documente le choix cuivre 1oz et met a jour les fichiers de fab
    Garde 1oz (standard) plutot que 2oz (+18$/lot) pour ce proto -
    temperature mesuree pendant les tests plutot que supposee, upgrade
    possible plus tard si besoin. Fichiers Gerber/BOM/PickAndPlace
    regeneres suite au rework du layout (condensateurs electrolytiques
    plus gros, plan de masse refait).
    [BOM_Board1_PCB1_2026-07-11.xlsx, PickAndPlace_PCB1_2026_07_11.xlsx]
2026-07-15 Ajoute le rendu 3D du proto TAS5825M
    Vue 3D EasyEDA du board final : puce, condensateurs electrolytiques a
    leur vraie taille, connecteurs et circuit de protection en place.
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2026-08-17 Corrige le pad 33 non relie a GND et documente le routage refait
    Le pave expose de U1 etait reste en l'air au schema. Consequence : le
    cuivre sous la puce formait un ilot flottant, le plan de masse le
    contournait au lieu d'y entrer, et les 16 vias thermiques descendaient
    vers un second ilot isole. Effet double, thermique (la chaleur ne
    pouvait s'evacuer que dans deux petites plaques au lieu du plan entier)
    et electromagnetique (surface flottante sous la puce, a cote des noeuds
    de commutation).
    Ce defaut n'est signale ni par la DRC ni par le rendu 2D : un pad ou un
    via sans net n'est pas une violation de regle, juste du cuivre inutile.
    D'ou la trace ecrite, et le test qui fait foi (le cuivre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
2026-08-18 Consigne l'etat de reprise du proto et les references LCSC verifiees
    Le document change de lecteur : dans deux semaines c'est l'etudiant qui
    a lance le projet qui reprend. Il doit pouvoir savoir ou en est la carte
    sans relire tout l'historique.
    Ajoute une section 0 "Etat au 2026-08-18" : ce qui est verifie sur les
    gerbers (et non dans l'editeur), ce qui bloque la commande, et le seul
    point mineur restant. La carte n'est pas commandee.
    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
    [BOM_Board1_PCB1_2026-08-18.xlsx, PickAndPlace_PCB1_2026_08_18.xlsx]
2026-08-18 Ouvre le chantier alimentation, jamais instruit au-dela du dimensionnement
    La section 8 donnait un ordre de grandeur (rail 24 V, 500-600 W, facteur
    de crete) mais rien de ce qui se trouve entre l'alim et les puces.
    Le point qui commande tous les autres : l'impedance des haut-parleurs
    n'apparait dans aucun document et aucun modele n'est choisi. C'est elle
    qui fixe la puissance par voie, donc le budget d'alimentation et le
    choix de PVDD. Tant qu'elle n'est pas tranchee, le 500-600 W reste une
    estimation sans ancrage.
    Le point le plus susceptible de mordre : ~13 modules portent environ
    10 mF de capacite de reserve au total. Un SMPS de 600 W part en securite
    ou fait disjoncter sur une capacite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
2026-08-18 Pose la carte des decisions systeme, des HP au chassis
    Les cinq deviations trouvees le 18/08 - PDN non route, connecteur a une
    seule masse, sub bridge incompatible avec le 8 ohms, origine du 3.3 V,
    selfs sous la spec TI - sont toutes venues d'une discussion sur la
    finalite, aucune de la relecture du schema ou du PCB. Ce sont des
    questions d'interface, et chaque bloc etait correct isolement.
    Ce document rend donc visibles les frontieres entre sous-systemes, la ou
    se logent les erreurs qu'aucune DRC ne voit. Chaque bloc donne ce qui
    est decide, ce qui est ouvert, et ce dont il depend.
    Trois interfaces jamais posees en sortent :
    Le bus TDM doit atteindre trois cartes meres physiquement separ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
2026-08-18 Corrige le compte de slots TDM : 25 et non 26
    Le sub fonctionne en mono (PBTL) et ne consomme donc qu'une seule voie,
    pas deux. Le total est 12 cartes x 2 + 1 = 25 slots, ce qui tombe
    exactement sur les 25 haut-parleurs. Le port 2 passe de 10 a 9 slots
    occupes.
    Erreur sans consequence materielle mais qui aurait fausse la
    repartition des slots au firmware.
2026-08-18 Ouvre la mecanique du coffret : rack 3U ventile, cartes debout
    La mecanique etait le dernier bloc entierement vide de la carte des
    decisions, ou elle apparaissait trois fois comme dependance. Elle
    contraint l'electronique en retour, ce qui la rend urgente : le format
    debout fixe l'emplacement des connecteurs, donc le routage.
    3U retenu. Quatre raisons qui se cumulent, dont une decisive : le 3U
    permet des ventilateurs de 120 mm, radicalement plus silencieux qu'un
    80 mm a debit egal. Dans un lieu d'ecoute c'est le critere qui tranche.
    Le 3U laisse aussi la place a l'alimentation interne et preserve le pas
    de 20 mm entre cartes, contraint par la circulation d'air.
    Cartes ampli debout, enfiche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
2026-08-18 Corrige le choix d'alimentation et cote ce qui a pu etre verifie
    La serie Mean Well LRS est ecartee : contrairement a ce qui avait ete
    suppose, elle embarque un ventilateur des 350 W, la convection ne
    couvrant que jusqu'a 150-200 W. Un ventilateur de 40 mm dans l'alim
    serait la source de bruit la plus aigue du rack, ce que le choix du 3U
    cherchait precisement a eviter.
    Retenue a la place : UHP-350-24, 350 W, veritablement en convection,
    94 % de rendement, et surtout 62 mm de large contre 124. La contrainte
    d'encombrement du chapitre 2 se desserre d'elle-meme : l'alimentation
    tient a cote des trois cartes meres sans superposition.
    350 W suffisent. La consommation moyenne sur programme music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
2026-08-18 Modelise l'implantation 3U en OpenSCAD et tranche la taille de la carte
    Le fichier est parametrique et verifie les degagements plutot que de
    seulement les dessiner : largeur, hauteur, profondeur, panneau arriere
    et ventilation sont controles par des echo() qui affichent OK ou
    DEPASSE. Etant du texte, il vit dans le depot et se diffe comme le reste
    de la documentation.
    Premiere passe : la largeur depassait de 5 mm. Reduction de l'ecart
    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
    [implantation-3u.scad]
2026-08-18 Corrige l'affichage : enveloppe en fil de fer, plus de transparence
    L'apercu OpenSCAD gerait mal la boite translucide qui enveloppait toute
    la scene : l'ordre de rendu des faces transparentes est imprevisible, et
    une grande boite a 12 % d'opacite contenant tout le modele donnait un
    rendu blanchatre ou rien n'etait lisible.
    L'enveloppe du rack devient un fil de fer, douze aretes en barres fines.
    Les autres volumes passent en opaque, la transparence n'apportant rien
    ici et posant le meme probleme a moindre echelle.
    Ajoute aussi le rappel d'usage en tete de fichier : F5 pour l'apercu, et
    View > View All si la vue reste vide - le modele fait 450 mm de large et
    la camera par defaut ne s'y ajust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
    [implantation-3u.scad]
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2026-08-18 Passe la ventilation en push-pull et decale le panneau arriere
    La direction du flux n'est pas un choix : les cartes debout creent des
    canaux avant-arriere, un flux lateral buterait sur leur tranche et les
    contournerait. Les ventilateurs sont donc tous sur cet axe.
    Sur cet axe en revanche, souffler a l'avant et extraire a l'arriere
    double le differentiel de pression disponible. Sur un chemin degage ce
    serait marginal, mais les canaux ne font que 8 mm et cette restriction
    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
    [implantation-3u.scad]
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2026-08-18 Ajoute les rendus 2D et 3D de la carte dans son etat final
    Exportes le 2026-08-18 a 16h42 et 16h49, soit apres le dernier export
    gerber de 13h50. Ils montrent donc la carte corrigee : quatre trous a
    Ø 3.30 sur entraxe 45 x 51, couture de masse posee, pad 33 relie.
    Les rendus precedents avaient ete volontairement laisses de cote parce
    qu'ils datavaient d'avant ces corrections et auraient contredit le texte
    des documents qui les accompagnent.
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2026-08-18 Ajoute le mode superviseur et tranche la question de la source audio
    Le Raspberry Pi devient une cible de production et non plus seulement de
    banc, ce qui change le role du MCU sur la carte d'adaptation : il n'est
    plus un hote, c'est un superviseur qui cohabite avec le Pi.
    La regle « un seul hote a la fois » etait trop grossiere. Ce qui ne doit
    pas etre duplique, c'est la source d'horloge. Un Pi et un ESP32
    cohabitent tres bien en se partageant les roles : le Pi pilote
    BCLK/LRCLK/SDIN, l'ESP32 garde l'I2C, PDN et les lignes de defaut. Le Pi
    ne touche jamais a l'I2C, ce qui evite le multi-maitre.
    Le superviseur repare surtout le piege d'ordonnancement documente au
    paragraphe precedent, qu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
2026-10-23 Propose un brochage pour le socket carte ampli / carte mere
    La carte d'adaptation et la carte ampli v2 vont etre routees, et toutes
    deux dependent du meme brochage. Le doc ne donnait que le contenu des
    deux connecteurs, pas l'ordre des broches ni le type de piece.
    Le brouillon place chaque PVDD face a son PGND et chaque horloge ou
    donnee face a une masse, pour garder les boucles de courant minimales.
    Il reste marque comme proposition : il ne sera fige qu'avec le routage
    de la carte ampli v2.
    Il corrige au passage une hypothese implicite : les ~6 A annonces pour
    deux broches en parallele supposent 3 A par contact, alors que beaucoup
    d'embases 2,54 mm sont donnees pour 1 A. Les sorties HP pa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
